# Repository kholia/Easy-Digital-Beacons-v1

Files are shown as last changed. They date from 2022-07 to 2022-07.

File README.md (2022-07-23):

### Easy-Digital-Beacons-v1

A simple and easy WiFi-enabled ESP8266-powered WSPR, FT8, and FT4 beacon system
which uses NTP + DS3231 RTC for timing. Also, checkout our [cost-effective, and
robust HF 5W PA system](https://github.com/kholia/HF-PA-v5/).

It is also a WiFi-enabled VFO, which is quite useful, and convenient for radio
experimentation work.

Note: The whole project can be assembled on a breadboard (including the [250mW
amplifier](./QRPp-Amplifier)) in under 30 minutes - do give it a go ;)

The whole design is modular, parametric (cost and others), field repairable,
and super extensible. It is almost trivial to add support for more `beacon
modes`.

#### Build Steps

If you are using Windows OS, execute the following steps:

- Download this repository by [clicking here](https://github.com/kholia/Easy-Digital-Beacons-v1/archive/refs/heads/master.zip).

- Extract the downloaded zip file to a folder.

- Run the `setup_arduino_ide.bat` file inside this folder.

- Install https://github.com/me-no-dev/ESPAsyncWebServer library.

- Install https://github.com/me-no-dev/ESPAsyncTC library.

If you are on Linux, execute the following steps:

```
sudo apt-get install git  # install 'git' if needed

git clone https://github.com/kholia/Easy-Digital-Beacons-v1.git

make install_arduino_cli
make install_platform
make deps  # using Windows?, read the 'Makefile' file

cd ~/Arduino/libraries
git clone https://github.com/me-no-dev/ESPAsyncWebServer.git
git clone https://github.com/me-no-dev/ESPAsyncTCP.git
```

Now execute these common steps:

Add your WiFi credentials in `Easy-Digital-Beacons-v4/credentials.h` file

Change the following lines in the code to use your values:

```
char message[] = "VU3CER VU3FOE MK68";
char call[] = "VU3FOE";
char loc[] = "MK68";
uint8_t dbm = 27;
```

[OPTIONAL] Change the following line in the code to suit your Si5351A module:

```
int32_t si5351CalibrationFactor =  ...
```

Use [this program](https://github.com/etherkit/Si5351Arduino/blob/master/examples/si5351_calibration/si5351_calibration.ino)
to derive the calibration value for your Si5351A module.

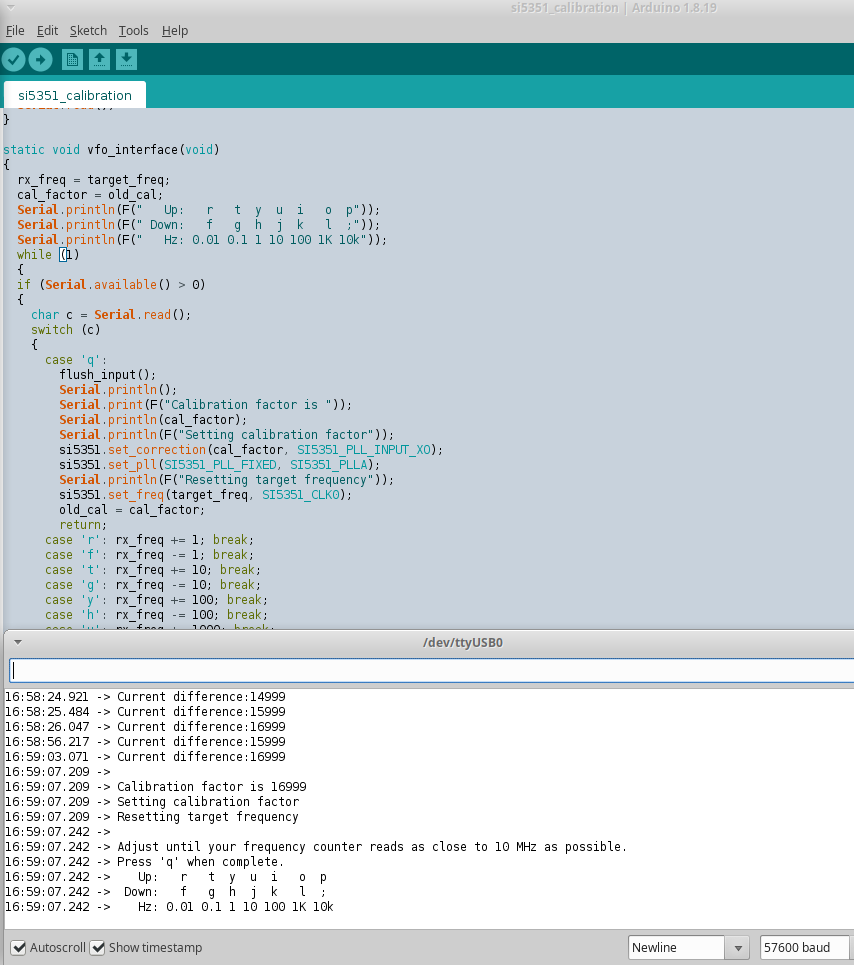
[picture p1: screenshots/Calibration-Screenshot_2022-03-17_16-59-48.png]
Si5351A Calibration


Follow [this tutorial first](https://randomnerdtutorials.com/esp8266-web-server-spiffs-nodemcu/) to
get familiar with `SPIFFS` uploading stuff. Use the `Tools -> ESP8266 Sketch
Data Upload` option in the Arduino IDE to upload the webserver resources to
ESP8266. Note: The webserver resources are located in the `data` folder
inside the `Easy-Digital-Beacons-v4` sketch.

Open and upload the `Easy-Digital-Beacons-v4` sketch to ESP8266 using the
`Sketch -> Upload` option in the Arduino IDE.

You are all set for the next step - congrats!

#### Usage

Turn off the `SW1` switch, and reboot the beacon system. The beacon system now
connects to your WiFi, and then runs a web server.

This web server can be accessed at http://beacon.local URL typically.

Beacon's web interface:

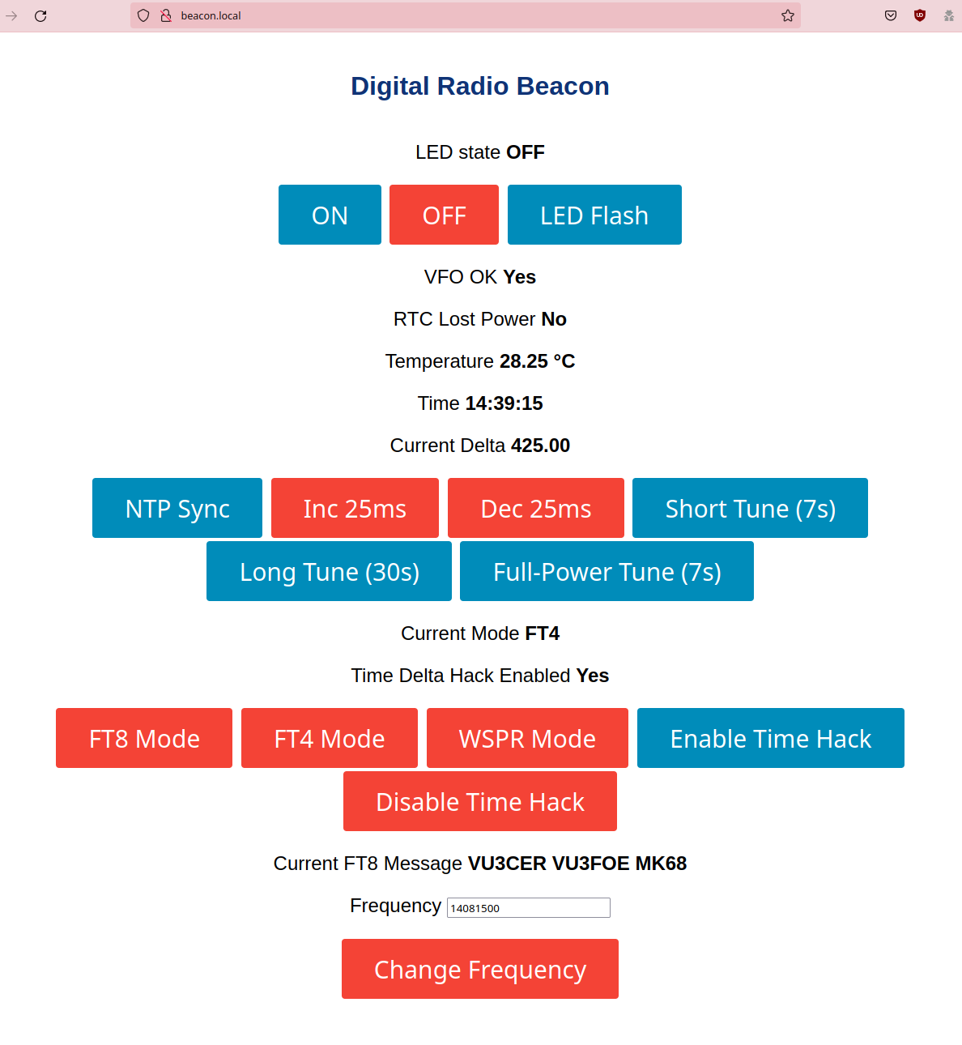
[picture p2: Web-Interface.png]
DEMO 2


Use this web interface to configure the beacon. Please use the `NTP Sync`
option in this web interface to set the RTC time fairly correctly.

Now, turn on the `SW1` switch, and reboot the beacon system. The beacon system
is active now, and will TX as per the configuration.

TIP: Please use a local (or nearby) receiver to receive and decode the beacon
signals! This is important to ensure that your beacon is TX'ing correctly.

Pinout 1


Si5351A module is connected via I2C to pins D1 (SCL) and D2 (SDA) of the Wemos
D1 Mini board. Connect DS3231 similarly.

Here is the schematic for the `Easy-Digital-Beacons-v4` sketch:

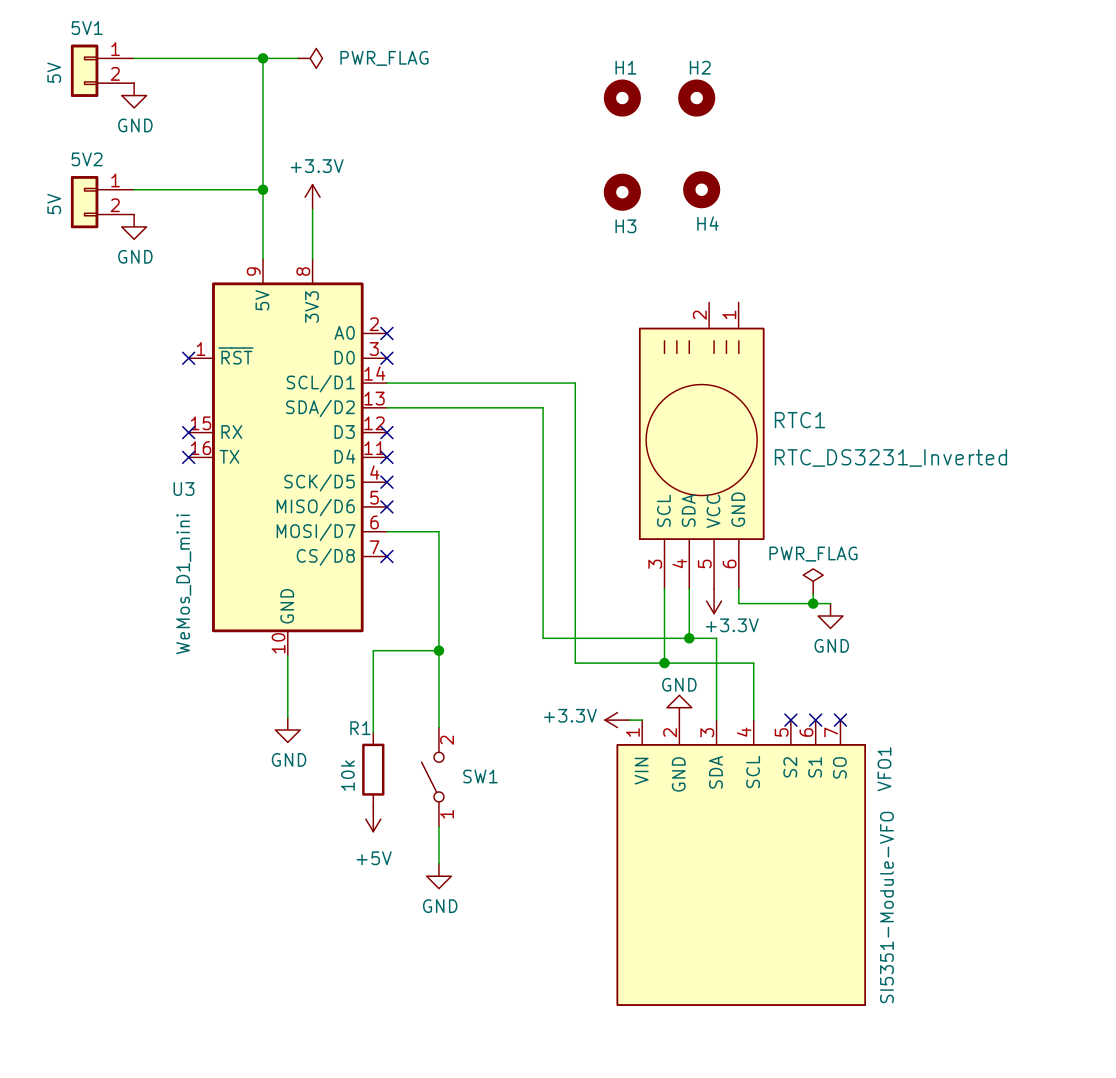
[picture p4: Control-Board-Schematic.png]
Schematic


For troubleshooting, you may want to try the following similar project by the
awesome WB2CBA:

- https://antrak.org.tr/blog/esp-wspr-simple-and-inexpensive-wspr-transmitter/
- https://antrak.org.tr/blog/a-whisper-wspr-adventure-and-esp_wspr/

#### Notes

Note 2 (March-2022): The `FT4` beacon is decently reliable now (all thanks to
Anupam).

Author: Dhiru Kholia (VU3CER) - https://www.qrz.com/db/VU3CER/

Author 2: Anupam Saikia - https://github.com/anupamsaikia

The `DT` timings are very nice with `NTP Sync`, `DS3231 RTC` and the optional
`time-delta hack`.

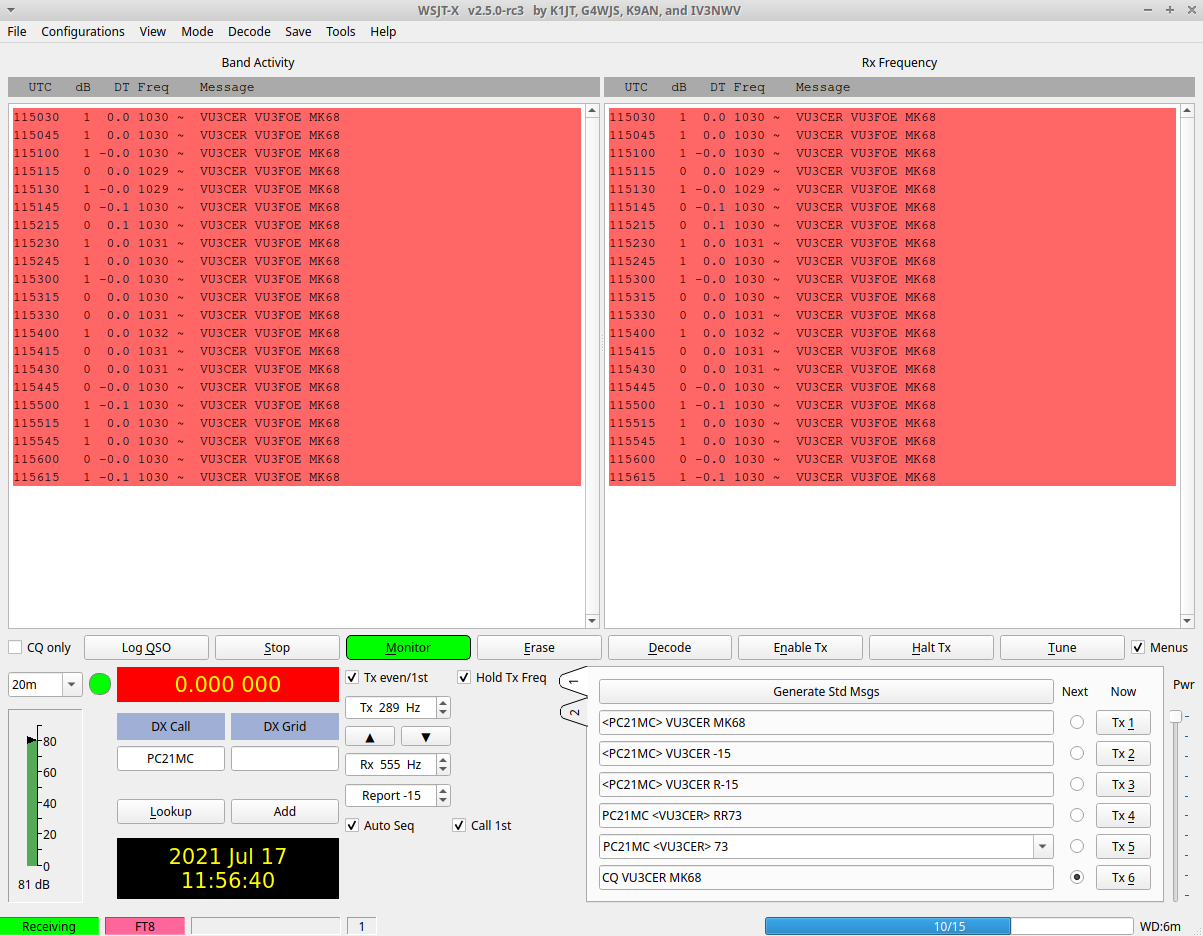
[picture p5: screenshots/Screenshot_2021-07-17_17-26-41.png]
DEMO 0


7W (or less) of HF RF power offers global communications coverage when
propagation is good:

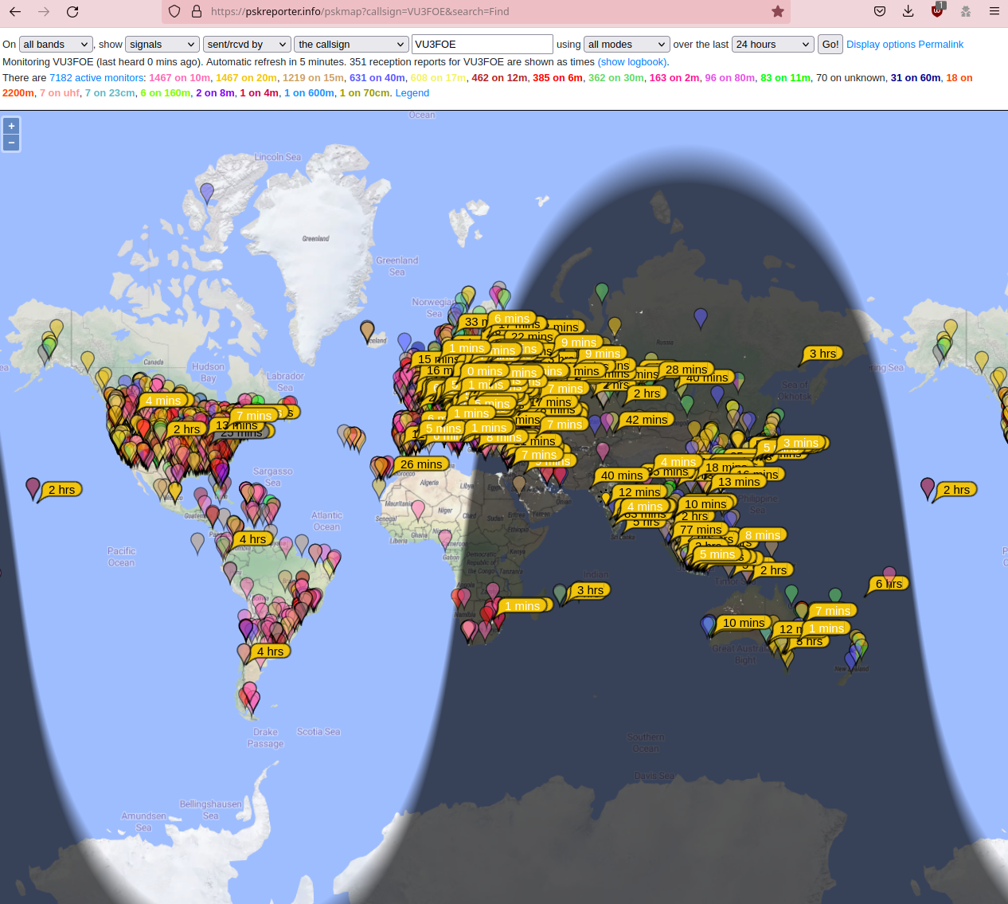
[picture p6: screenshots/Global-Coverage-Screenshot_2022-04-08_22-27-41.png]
Global Coverage

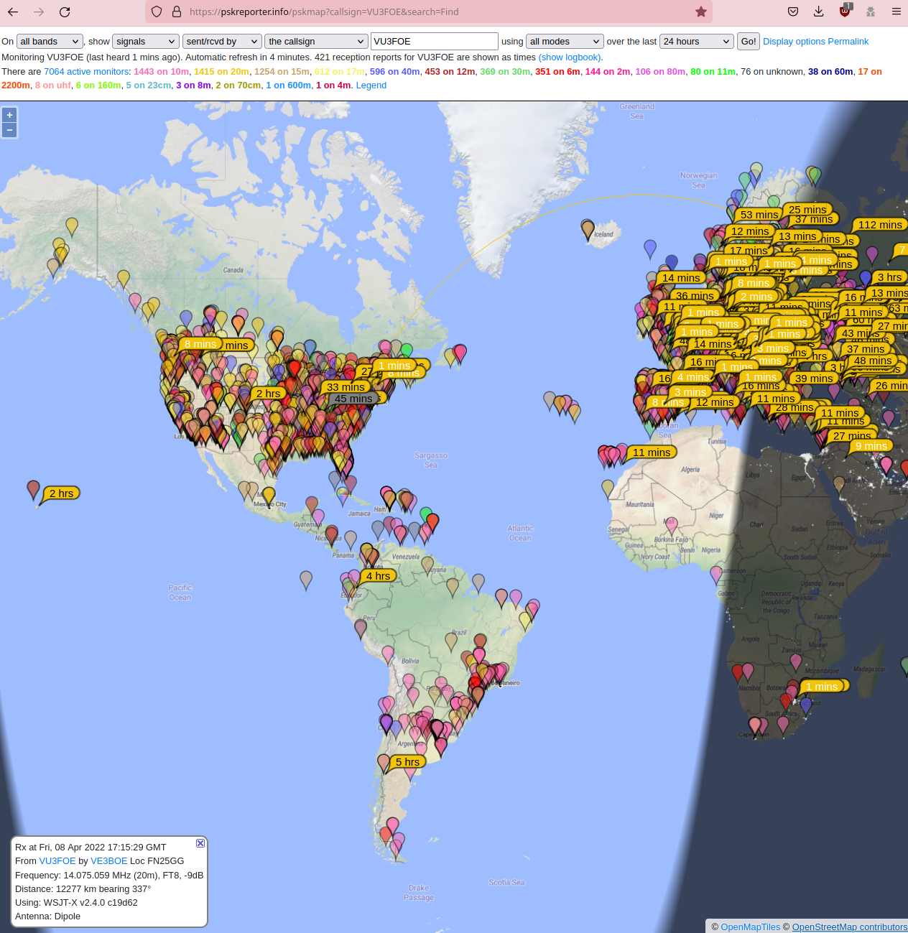
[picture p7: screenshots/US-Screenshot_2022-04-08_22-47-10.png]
US - Many Spots


WSPR mode demo:

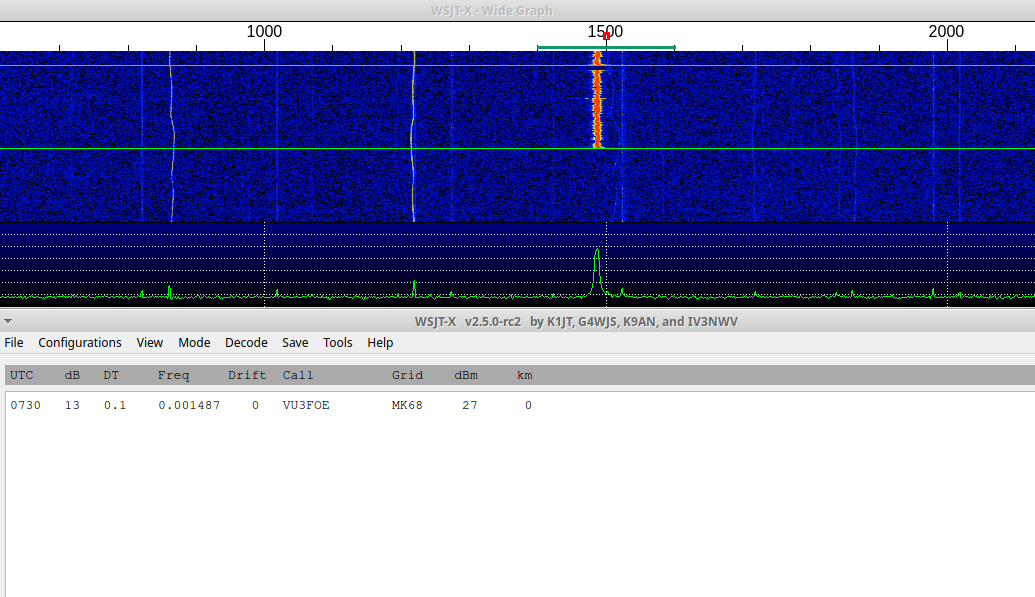
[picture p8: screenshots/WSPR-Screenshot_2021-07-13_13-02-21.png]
DEMO 1


Sample 3D rendering:

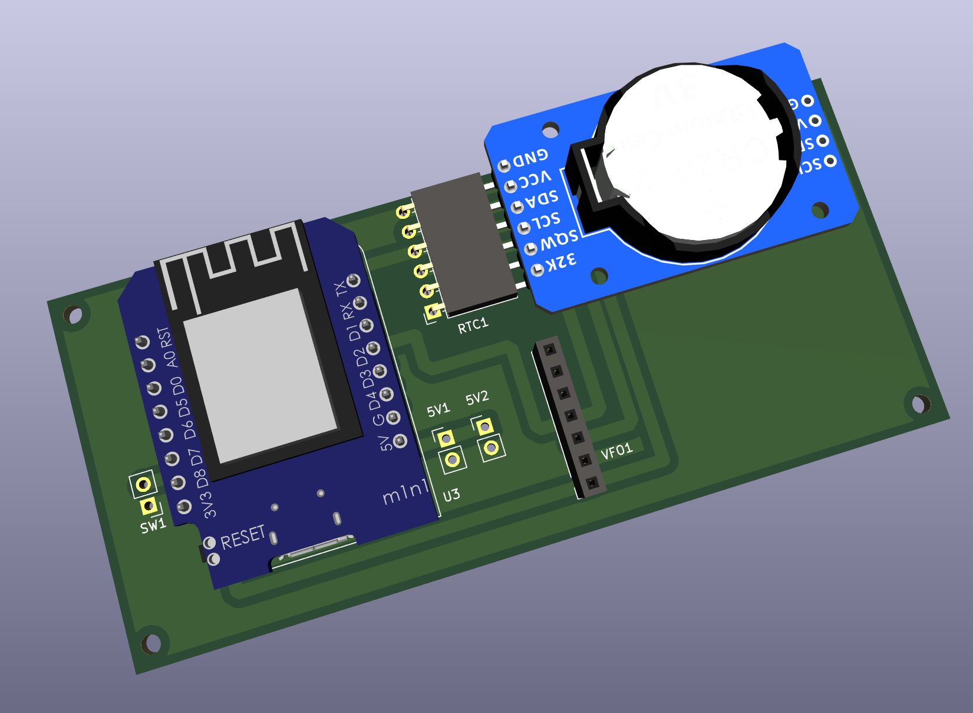
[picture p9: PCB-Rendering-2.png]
DEMO 3


Note: This 3D rendering is *only* published to help with the manual layout work
on Zero-PCBs. The current PCB version is just a placeholder hack - more to come
soon!

FT4 mode demo:

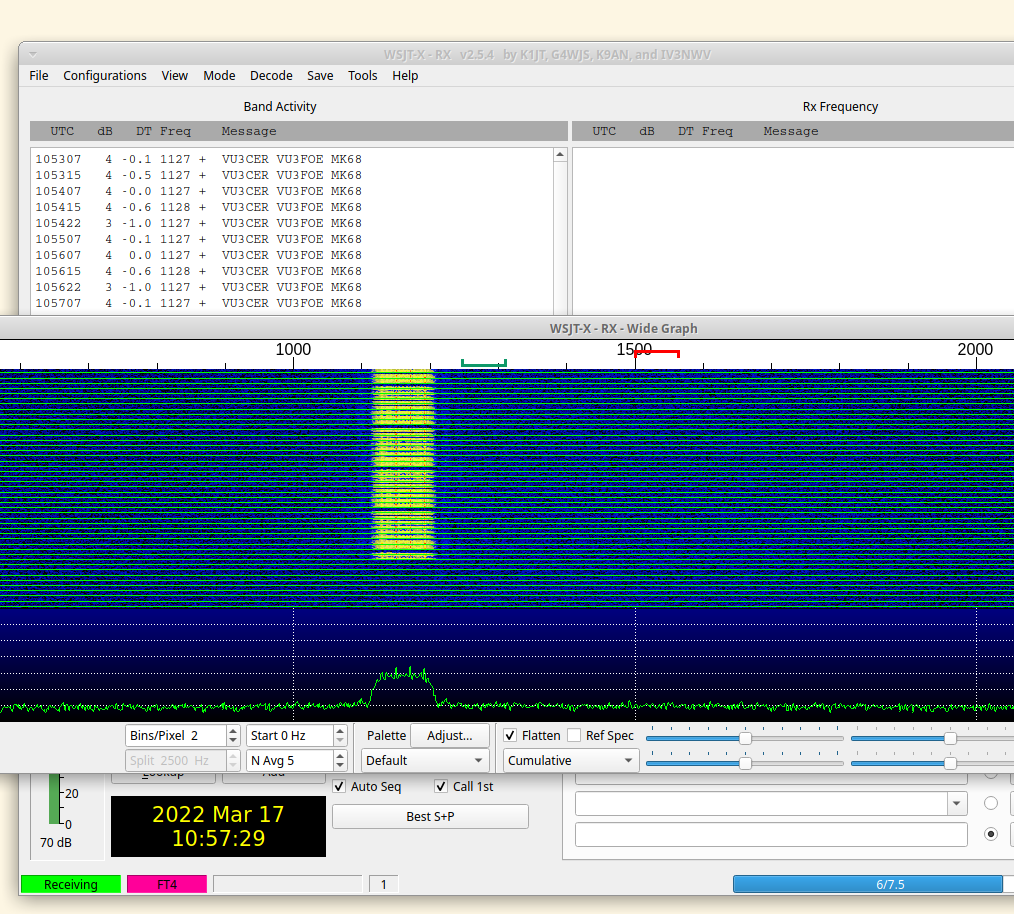
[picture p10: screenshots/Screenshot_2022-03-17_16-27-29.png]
FT4 1


FST4W mode demo:

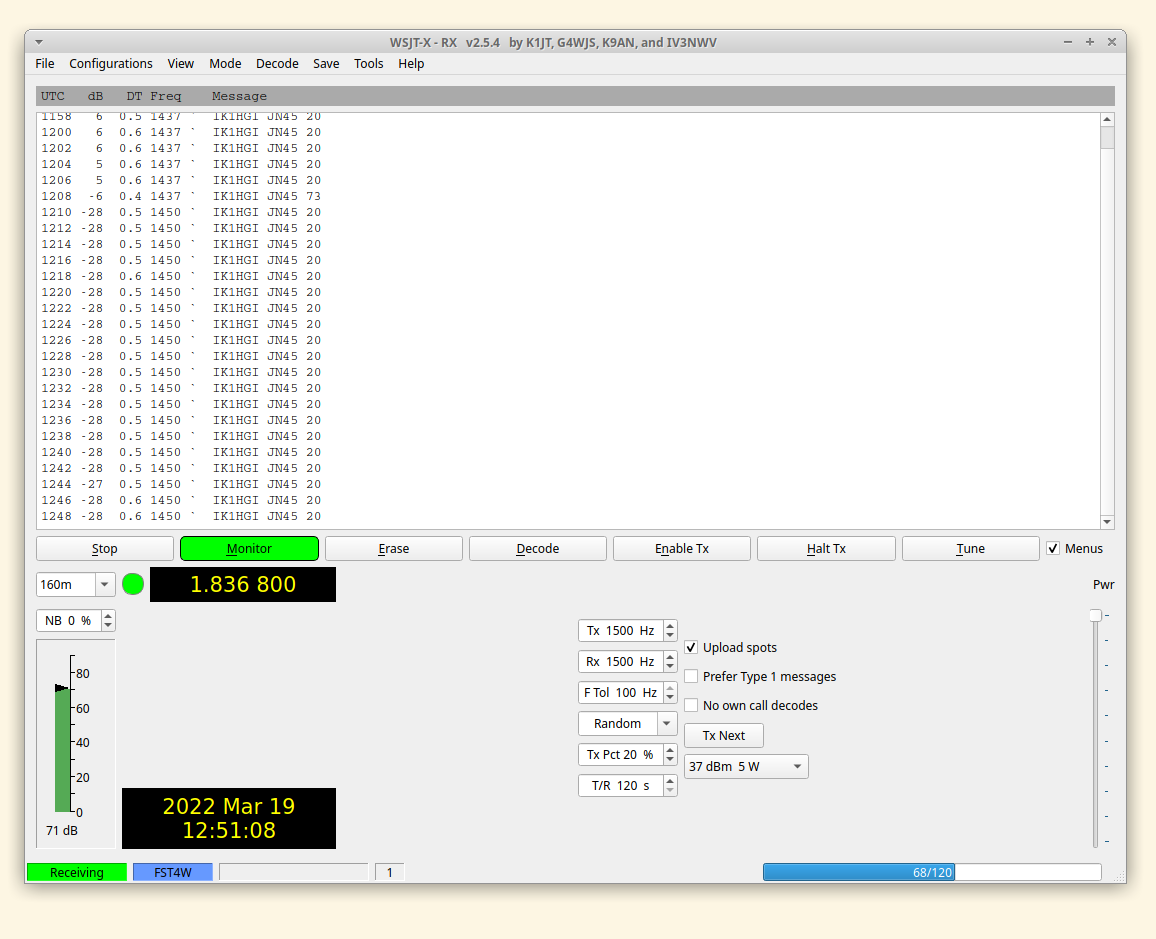
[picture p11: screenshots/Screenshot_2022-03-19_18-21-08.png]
FST4W 1


#### Battery System Recommendation

I recommend using a LiFePo4 (LFP) battery which has good energy density and is
also priced decently well.

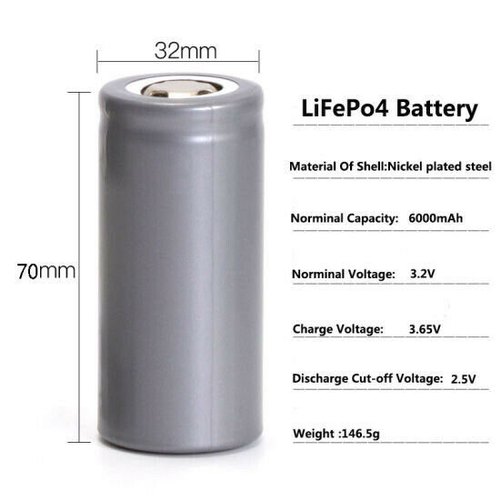
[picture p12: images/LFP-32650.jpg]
32650 battery


Use the LFP battery with a `1S LFP BMS`.

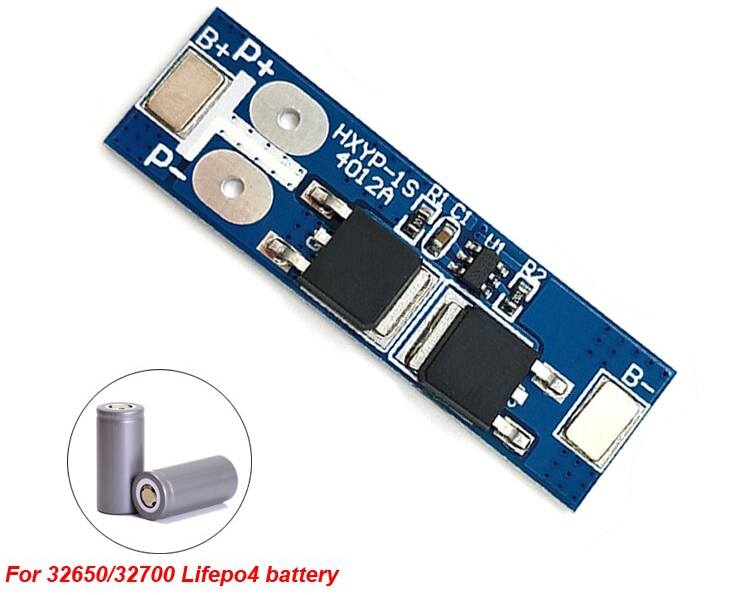
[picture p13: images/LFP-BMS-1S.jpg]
1S LFP BMS


The BMS' output can be connected directly to the 3.3v input of the ESP8266
module.

#### NTP (Time) Sync for FST4W-Antonio

In the Arduino IDE, select `Tools -> Serial Monitor`. In the `Serial Monitor`
send `s` character to ESP8266 to trigger the `NTP Time Sync` process.

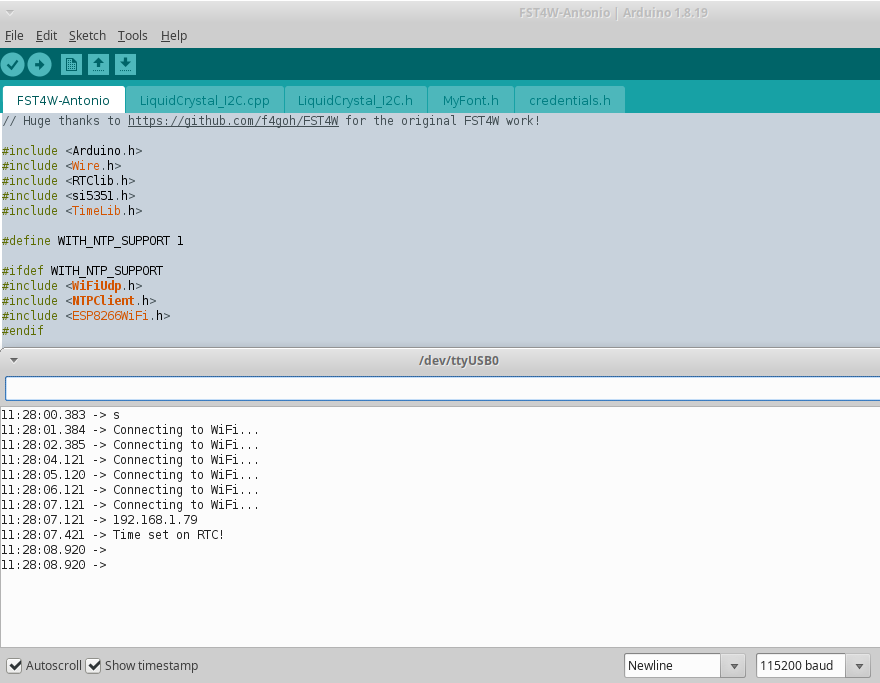
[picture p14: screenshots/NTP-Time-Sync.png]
NTP Time Sync


Reboot ESP8266 to check if RTC is retaining the correct time. If not, change
the RTC battery.

#### Power Notes

This will need a HF RF PA in most cases to be usable on the air.

UPDATE (May 2022): Checkout our [cost-effective, and robust HF PA system](https://github.com/kholia/HF-PA-v6/).

You can also start with the easy-to-build and breadboard-friendly [QRPp-Amplifier](./QRPp-Amplifier).

#### Relay Usage

We use a 2-channel relay as a `T/R switch`.

See https://github.com/kholia/Simple-TR-Switch for details.

Also check out https://github.com/kholia/Easy-Transceiver project.

#### BOM

- 1 x 3/5mm LED (purple or pink is recommended)

- 1 x small regular (spst) chassis mount switch

- 1 x 0.25w 470 ohm resistor (CFR / MFR)

- Relimate male connectors

- Relimate female-female cables

- Female berg strips

- Zero PCB of a suitable size

Si5351A Module:

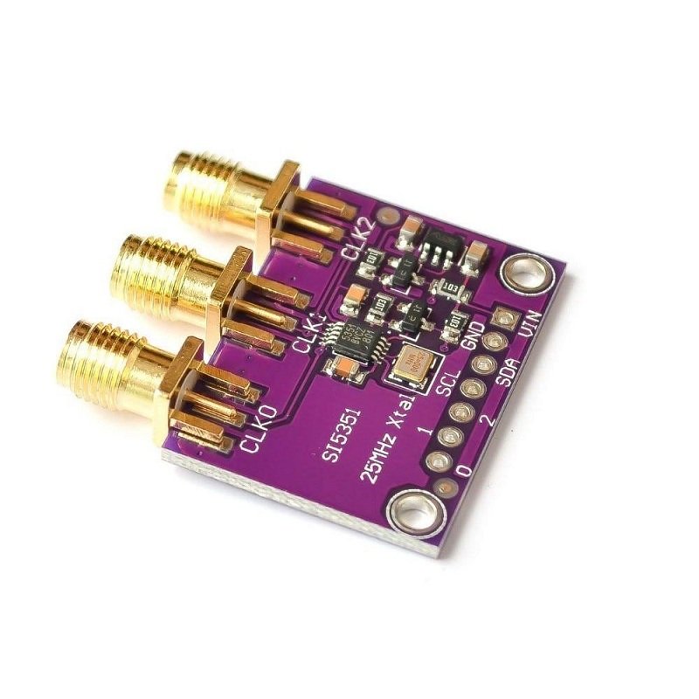
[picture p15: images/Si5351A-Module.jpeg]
Part 1


DS3231 RTC Module:

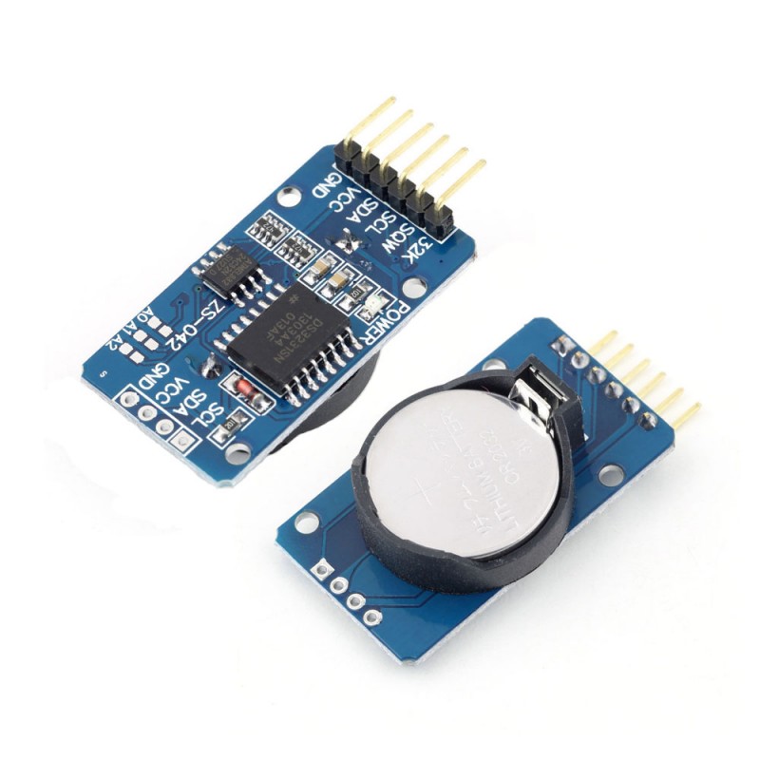
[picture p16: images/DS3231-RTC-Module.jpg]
Part 2


μC Board:

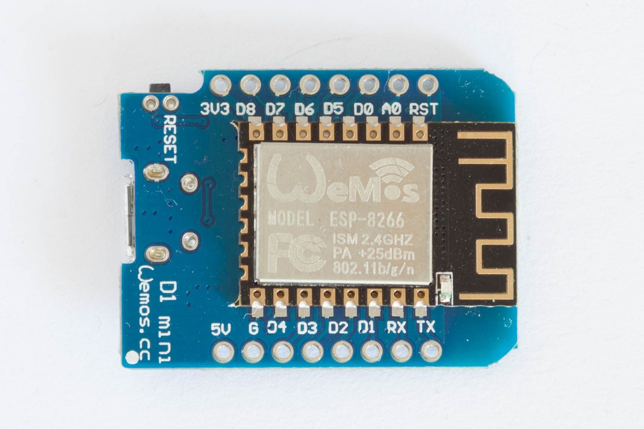
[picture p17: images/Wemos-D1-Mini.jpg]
Part 3


OLED screen (optional):

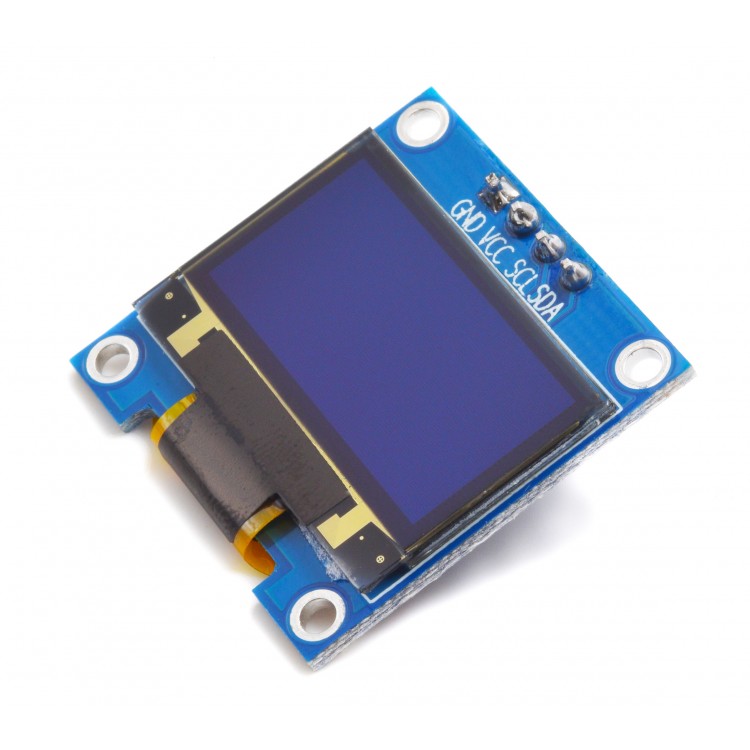
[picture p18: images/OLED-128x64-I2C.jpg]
Part 4


#### BOM Sources

- https://robu.in/

- https://www.electronicscomp.com/

- https://projectpoint.in/

#### Tips

Useful commands:

```
pacmd load-module module-null-sink sink_name=Virtual0
pacmd update-sink-proplist Virtual0 device.description=Virtual0
pacmd update-source-proplist Virtual0.monitor device.description=Virtual0
```

Use Gqrx and WSJT-X with a SDR device for initial frequency adjustment /
calibration. This is essential for WSPR functionality. FT8 is more
robust/tolerant of frequency deviations due to a much larger RX window.

Note: To customize the FST4W beacon to use your callsign and grid, use the
following commands to generate the `FST4Wsymbols` array data.

```
fst4sim.exe "IK1HGI JN45 20" 60 1500 0.0 0.1 1.0 10 -15 F > message.txt

message2array.exe message.txt
```

Replace the original `FST4Wsymbols` array data with the output of
`message2array.exe` program.

#### Future Tasks

- Change Si5351 calibration factor from the Web UI

- Add support for custom FT8 / FT4 messages

- Re-announce mDNS stuff [LP]

- EEPROM - save TX interval / schedule [LP]

- Reset to defaults button [LP]

#### References + Credits

- https://github.com/kholia/Easy-Transceiver

- https://github.com/kgoba/ft8_lib

- https://github.com/etherkit/JTEncode

- https://github.com/Naguissa/uEEPROMLib

- https://randomnerdtutorials.com/esp8266-web-server-spiffs-nodemcu/

- https://lastminuteengineers.com/ds3231-rtc-arduino-tutorial/

- https://learn.adafruit.com/adafruit-si5351-clock-generator-breakout/wiring-and-test

- https://github.com/agustinmartino/wsjt_transceiver

- https://github.com/agustinmartino/wsjtx_transceiver_interface

- https://www.qrp-labs.com/synth/ms5351m.html

- https://github.com/anupamsaikia - FT4 fixes - thanks!

- https://github.com/f4goh/WSPR (pretty cool)

- https://github.com/lu7did/PixiePi

- https://github.com/iw5ejm/multibandWSPR_nodeMCU

- https://km4nmp.com/2019/08/24/vfo-for-the-pixie-wiring-and-sketch-for-ad9850/

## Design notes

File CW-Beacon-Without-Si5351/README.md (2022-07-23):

Firmware can be downloaded from https://github.com/kholia/pico-cw-beacon-drs page.

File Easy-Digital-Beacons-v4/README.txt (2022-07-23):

Install the following libraries in the Arduino IDE.

https://github.com/me-no-dev/ESPAsyncTCP

https://github.com/me-no-dev/ESPAsyncWebServer

This version (Easy-Digital-Beacons-v4) operates with https://github.com/kholia/HF-PA-v5 (and others).

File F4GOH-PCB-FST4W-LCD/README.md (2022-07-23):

This program adds GPS functionality to the following code:

https://github.com/f4goh/WSPR/tree/master/src/IK1HGI/wsprEncode

Note: Connect TX pin of the NEO-6M GPS module to pin `D4` of Arduino Nano or to
the `TXGPS` pin on the F4GOH PCB board.

Connect `D3` pin to an external LED (via a resistor) for `GPS SYNC` indication.

On Arduino startup, it will automatically try to do a GPS time sync.

Launch the `Serial Monitor` (at a baud rate of 9600) and send the `g` command
to trigger a GPS update manually.

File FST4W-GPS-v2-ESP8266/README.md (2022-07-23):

Connect TX pin of the NEO-6M GPS module to pin `D7` of WeMos D1 mini.

Connect `D5` pin to an external LED (via a resistor) for TX indication.

Connect `D6` pin to an external LED (via a resistor) for `GPS SYNC` indication.

On ESP8266 startup, it will automatically try to do a GPS time sync for a
~minute.

Please power the `I2C LCD Display (16x2)` using 5v. It works poorly with
3.3v.

Launch the `Serial Monitor` (at a baud rate of 9600) and send the `g` command
to trigger a GPS update manually.

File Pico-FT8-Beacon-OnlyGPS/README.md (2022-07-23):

#### Connections

Pin 1 (GP0) is SDA and Pin 2 (GP1) is SCL - connect Si5351 module to these
pins. Connect GPS's TX pin to pin 12 (GP9) of Pi Pico.

#### Credits

- https://github.com/earlephilhower/arduino-pico

- https://github.com/etherkit/Si5351Arduino/blob/master/src/si5351.cpp

- https://github.com/kgoba/ft8_lib/

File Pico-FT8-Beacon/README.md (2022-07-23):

#### Connections

Pin 1 is SDA. Pin 2 is SCL. Connect GPS's TX pin to pin 12 of Pi Pico.

#### Credits

- https://github.com/earlephilhower/arduino-pico

- https://github.com/etherkit/Si5351Arduino/blob/master/src/si5351.cpp

- https://github.com/kgoba/ft8_lib/

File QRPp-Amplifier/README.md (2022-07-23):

#### Schematic

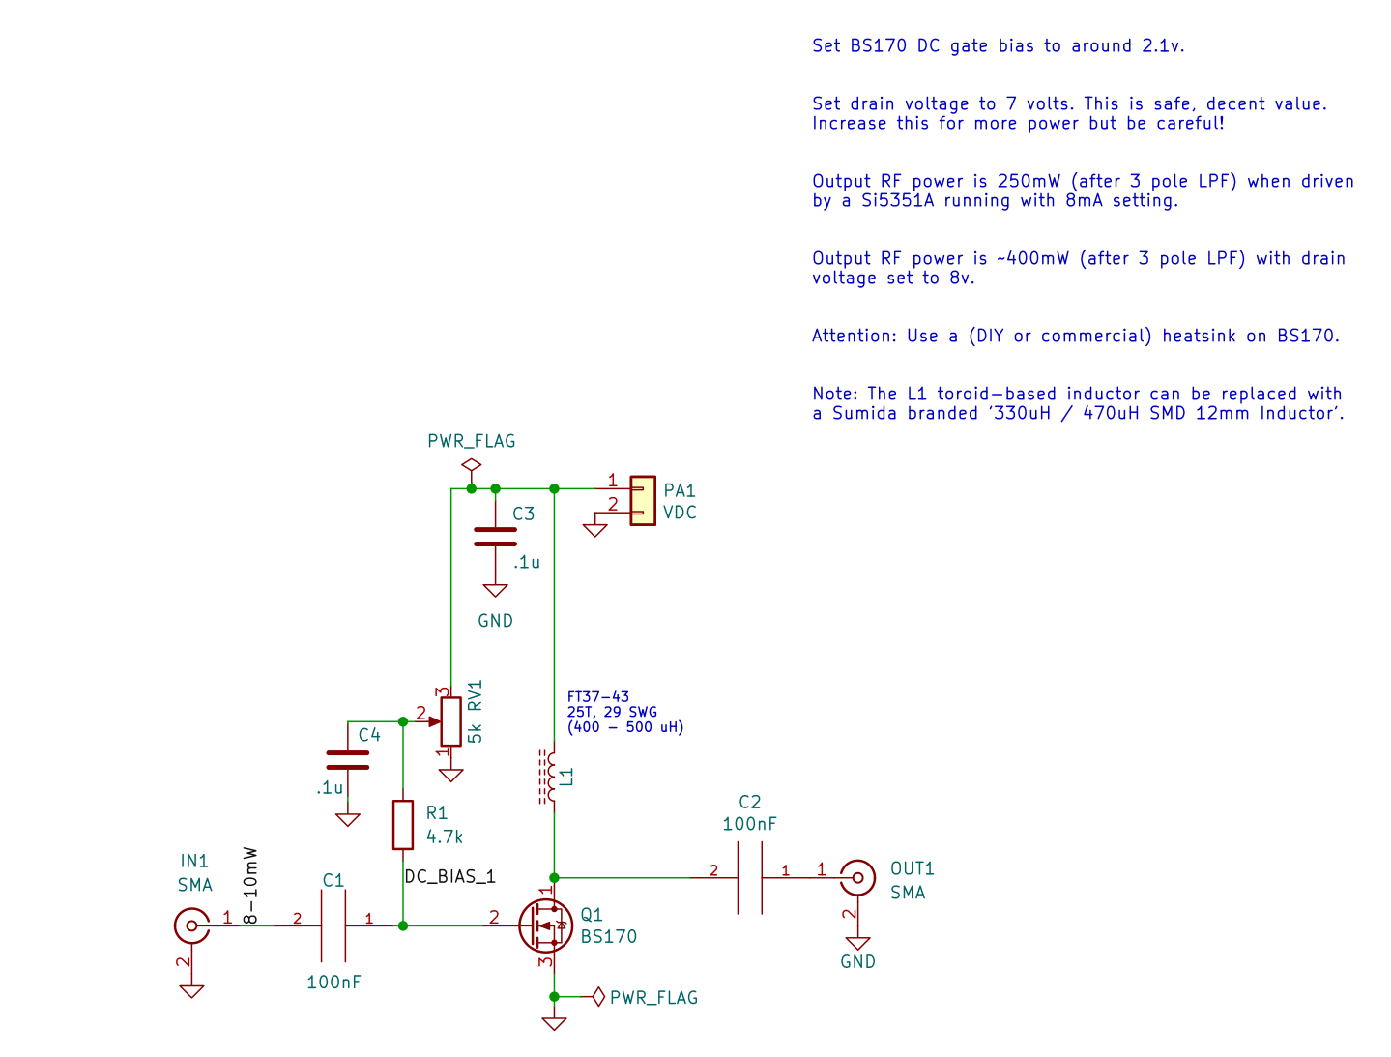
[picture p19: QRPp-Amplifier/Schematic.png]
Schematic


#### References

- https://www.instructables.com/DIY-Heatsink-for-Small-Transistors/ is superb

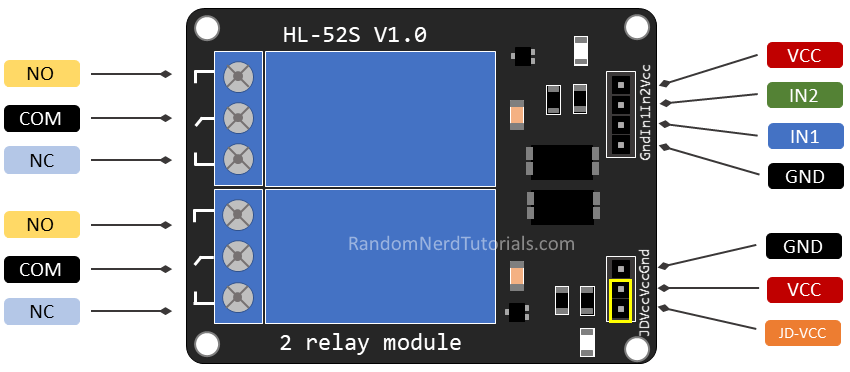
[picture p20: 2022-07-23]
images/Relay-pinout.png

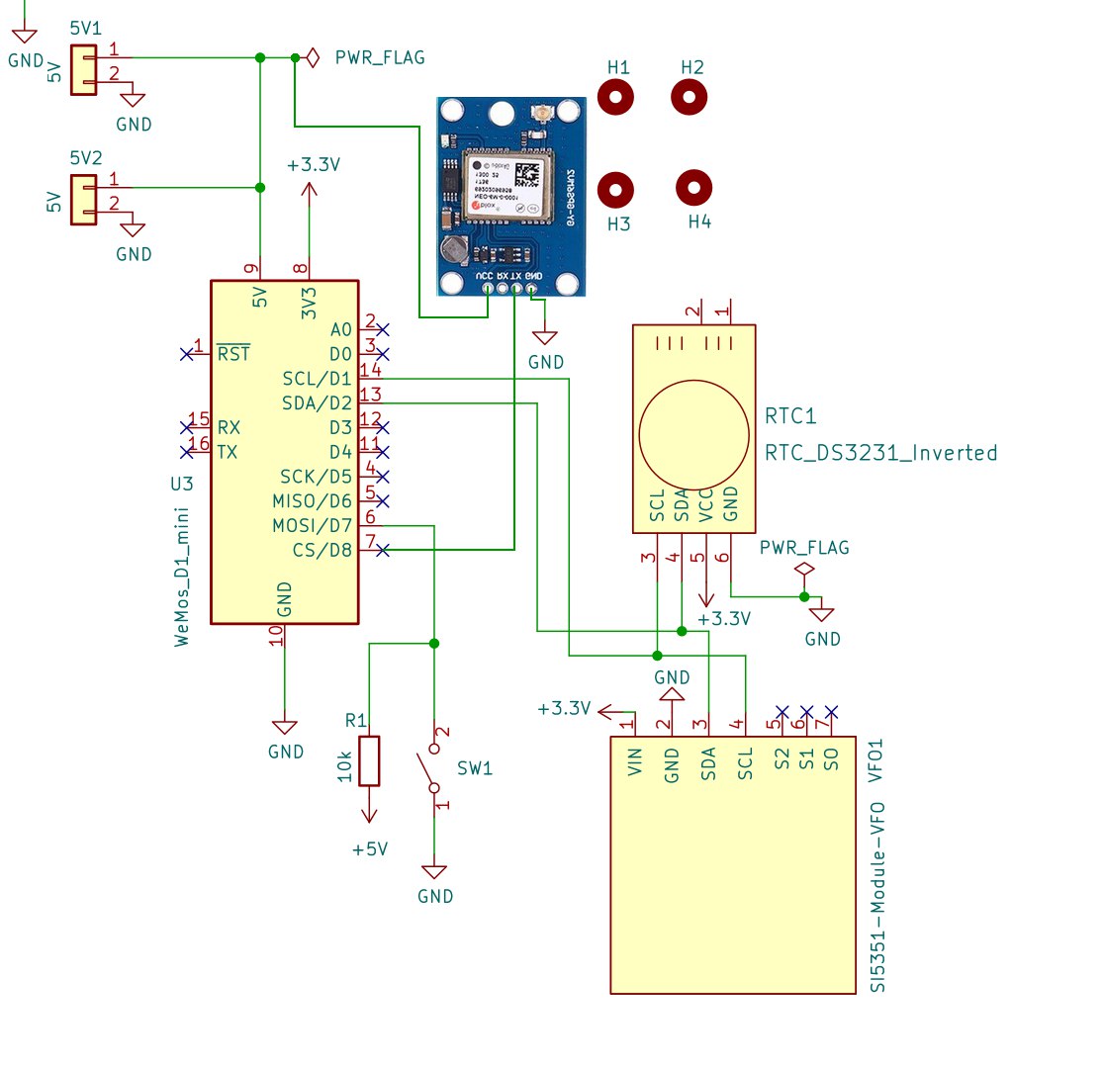
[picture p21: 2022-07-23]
images/Tony-Schematic.jpeg

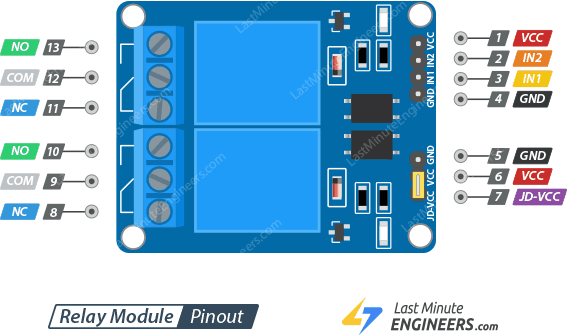
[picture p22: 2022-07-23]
images/relay-module-pinout.png

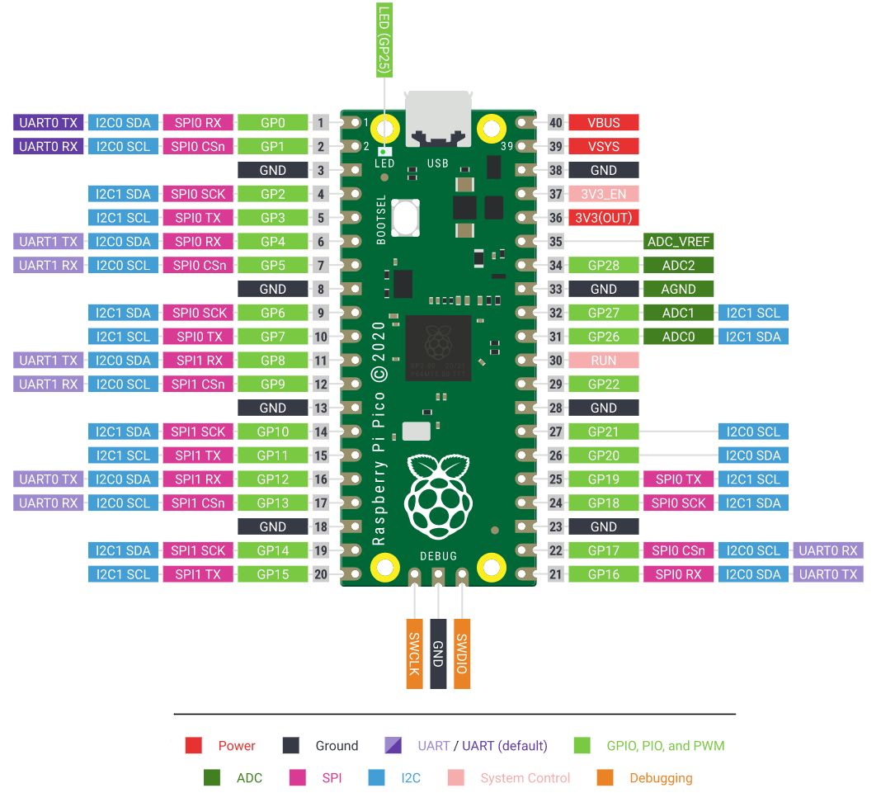
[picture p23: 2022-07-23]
Pico-FT8-Beacon-OnlyGPS/raspberry_pi_Pico-R3-Pinout-narrow.png

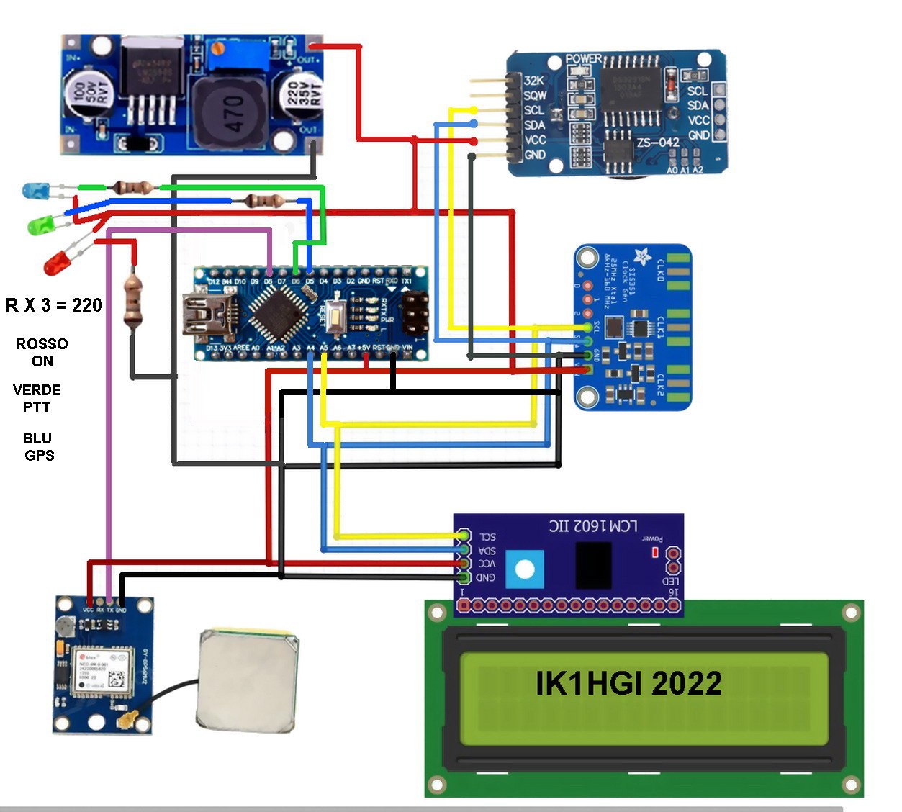
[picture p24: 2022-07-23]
WSPR-GPS-Antonio-Arduino/WSPR-GPS-Schematic-From-Antonio.jpg

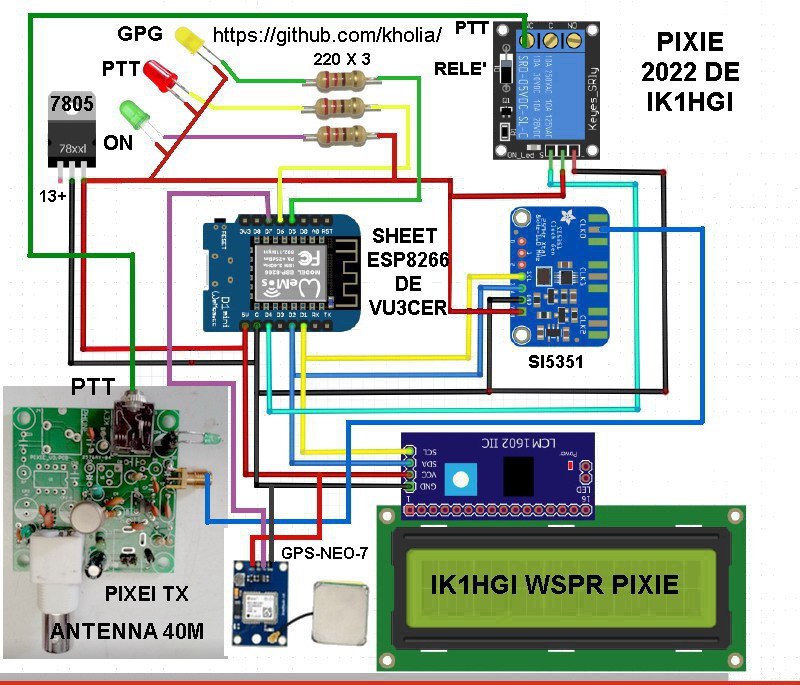
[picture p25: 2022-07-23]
Pixie-WSPR-ESP8266/Schematic.jpg

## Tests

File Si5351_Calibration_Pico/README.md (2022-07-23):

#### Connections

Note: Same pinout as `Pico-FT8-Beacon-OnlyGPS` from this repository.

#### Credits

- https://github.com/earlephilhower/arduino-pico

- https://github.com/etherkit/Si5351Arduino/blob/master/src/si5351.cpp

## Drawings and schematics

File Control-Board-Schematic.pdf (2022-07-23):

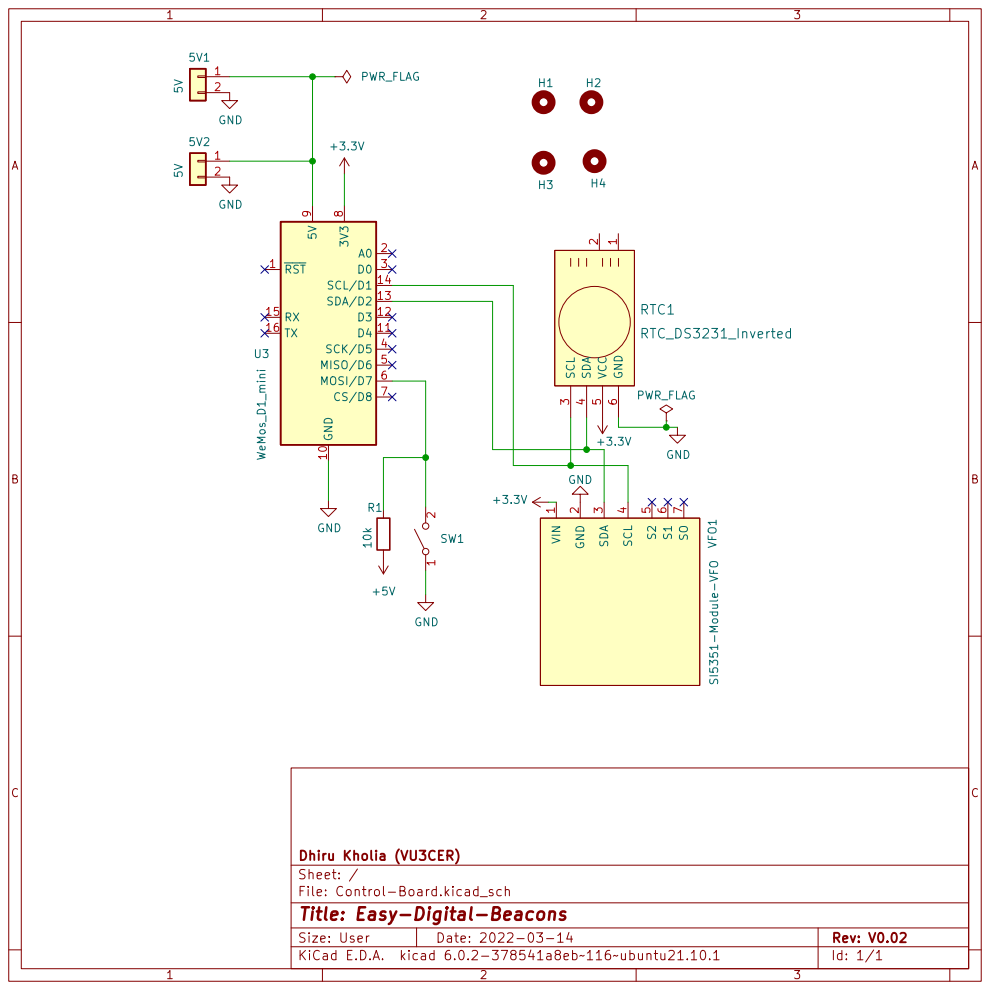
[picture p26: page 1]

File: Control-Board.kicad_sch Sheet: / Dhiru Kholia (VU3CER) GND

Id: 1/1 Title: Easy-Digital-Beacons

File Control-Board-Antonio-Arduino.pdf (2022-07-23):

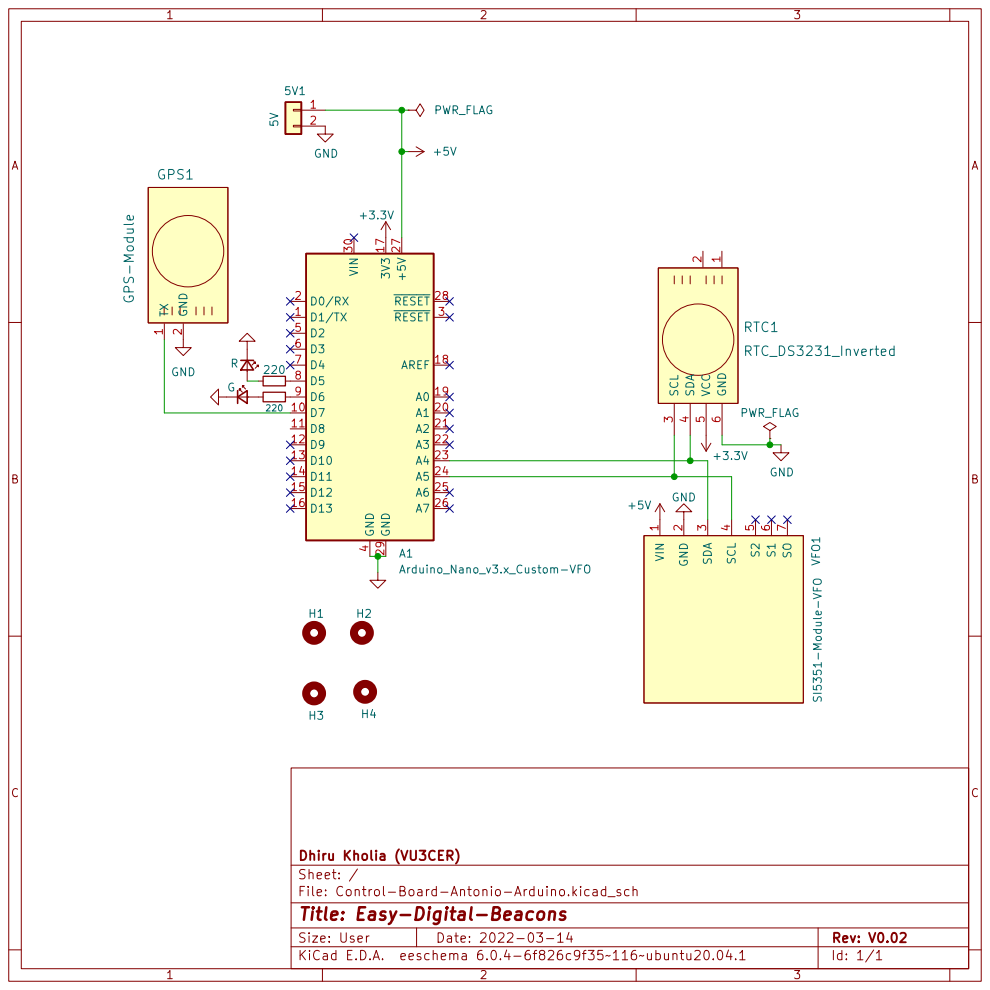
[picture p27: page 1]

2 GPS1 GPS-Module GND GND

Id: 1/1 Title: Easy-Digital-Beacons

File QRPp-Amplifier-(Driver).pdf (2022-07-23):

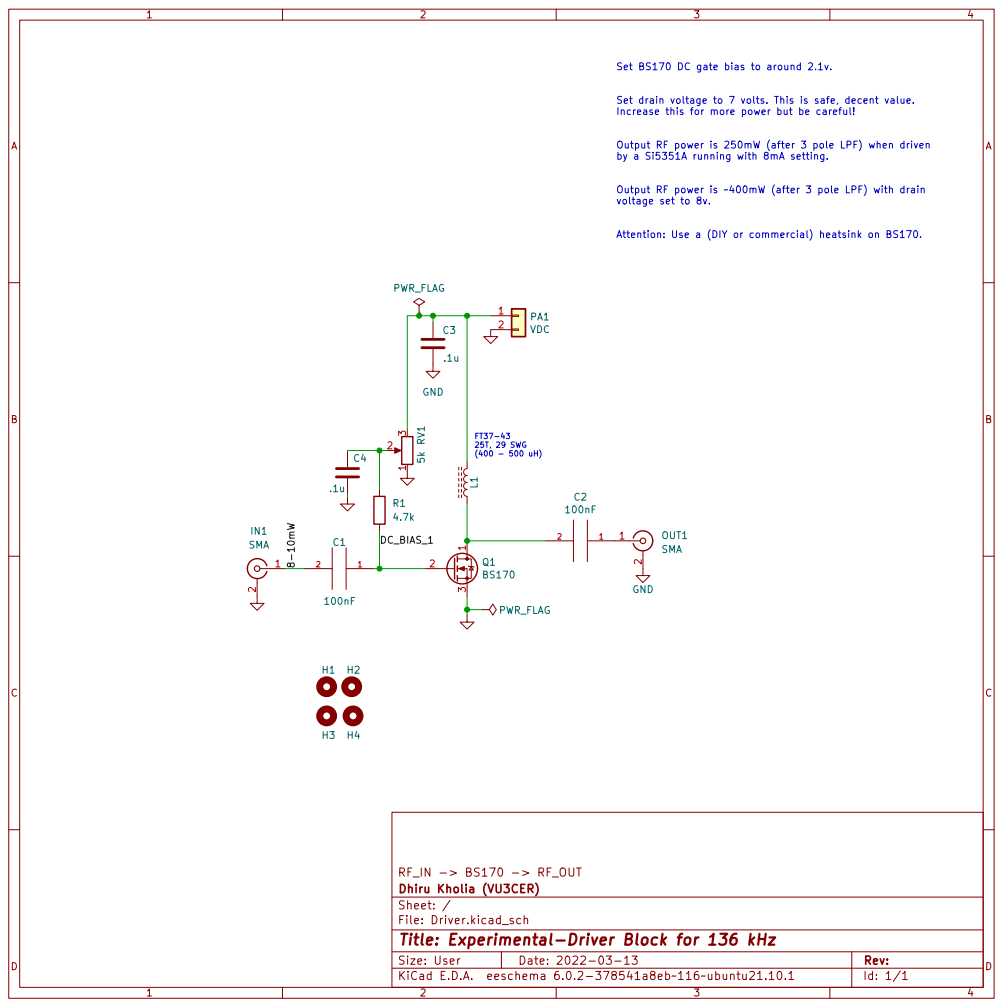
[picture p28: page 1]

Set drain voltage to 7 volts. This is safe, decent value.
Increase this for more power but be careful!

Output RF power is 250mW (after 3 pole LPF) when driven
by a Si5351A running with 8mA setting.

Output RF power is ~400mW (after 3 pole LPF) with drain
voltage set to 8v.

Attention: Use a (DIY or commercial) heatsink on BS170.

RF_IN -> BS170 -> RF_OUT
File: Driver.kicad_sch Sheet: / Dhiru Kholia (VU3CER)

Id: 1/1 Title: Experimental-Driver Block for 136 kHz

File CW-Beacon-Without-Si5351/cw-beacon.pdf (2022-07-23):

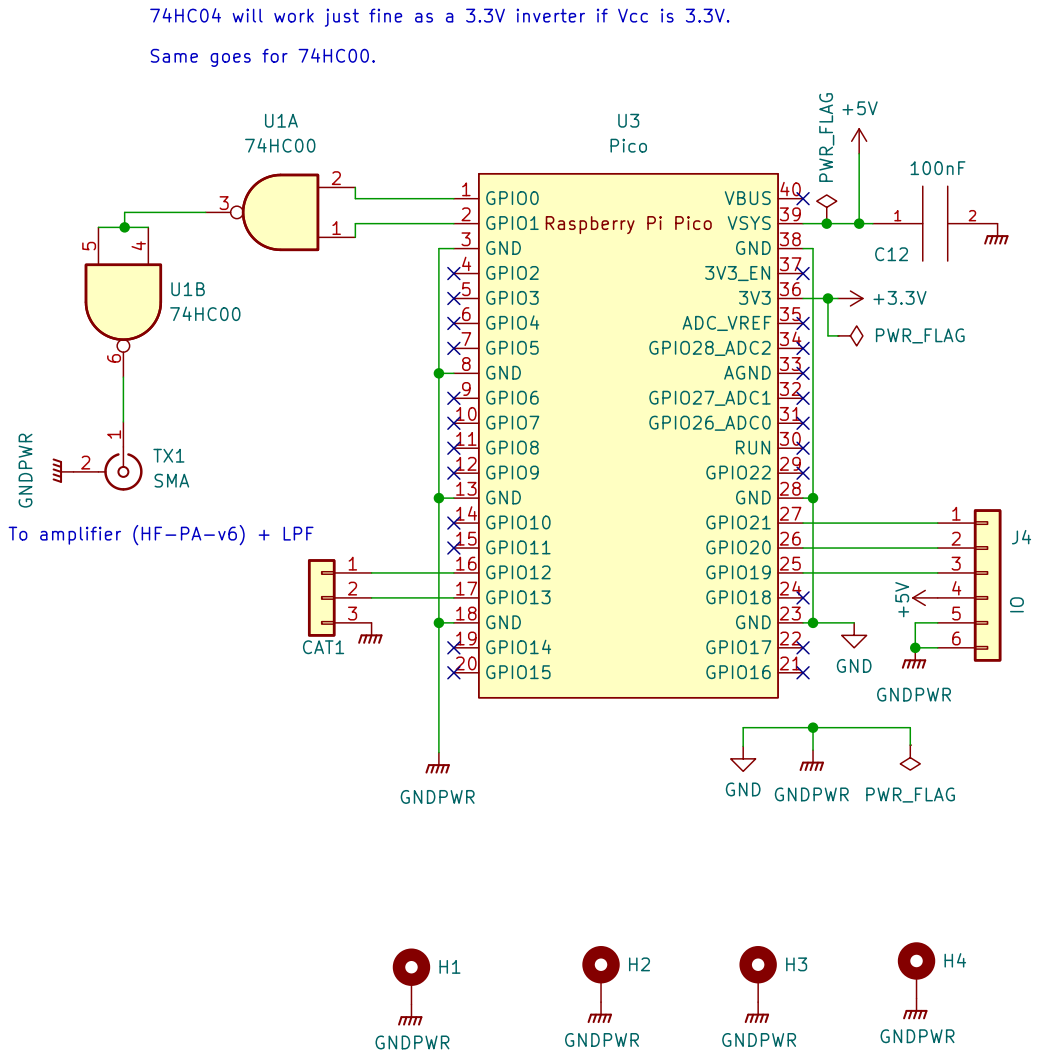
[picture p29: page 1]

74HC04 will work just fine as a 3.3V inverter if Vcc is 3.3V.

To amplifier (HF-PA-v6) + LPF

File: cw-beacon.kicad_sch Sheet: / VU3CER

Id: 1/1 Title: Easy CW Beacon without Si5351

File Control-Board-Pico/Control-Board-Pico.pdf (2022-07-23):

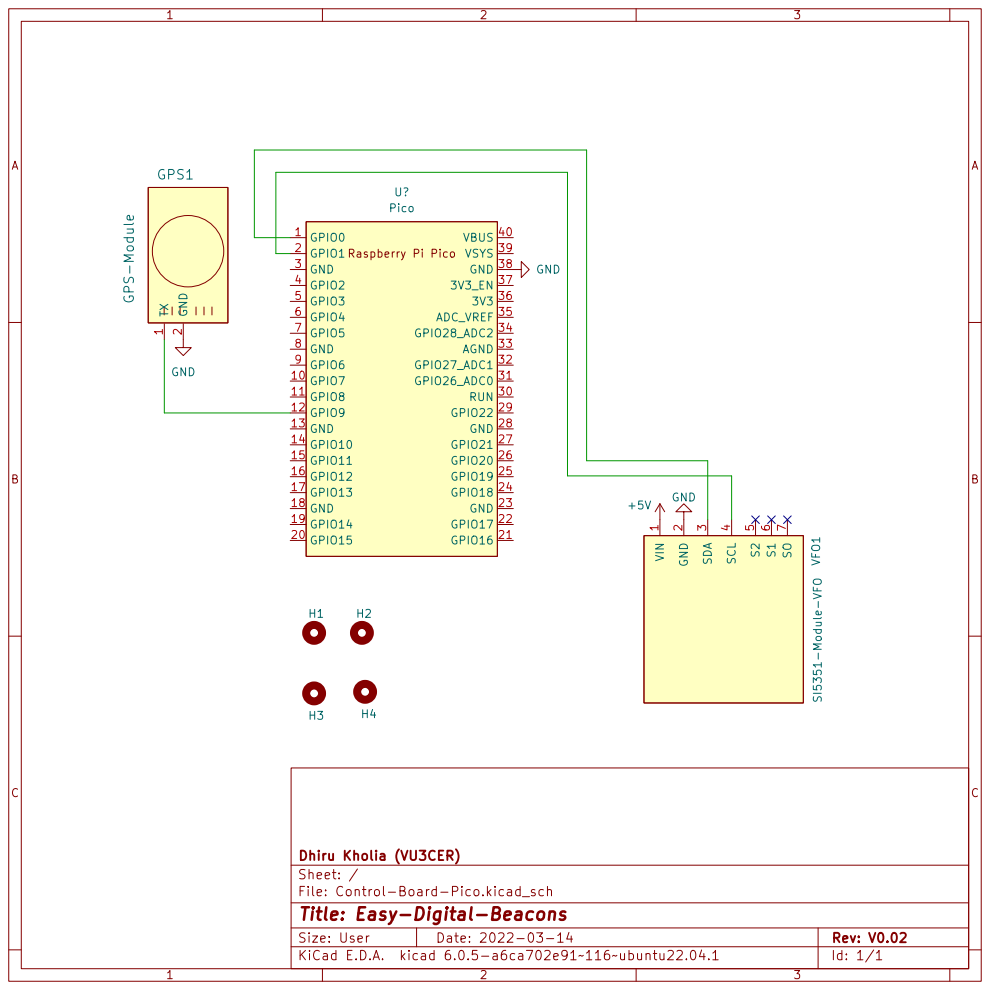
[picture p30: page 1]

Id: 1/1 Title: Easy-Digital-Beacons

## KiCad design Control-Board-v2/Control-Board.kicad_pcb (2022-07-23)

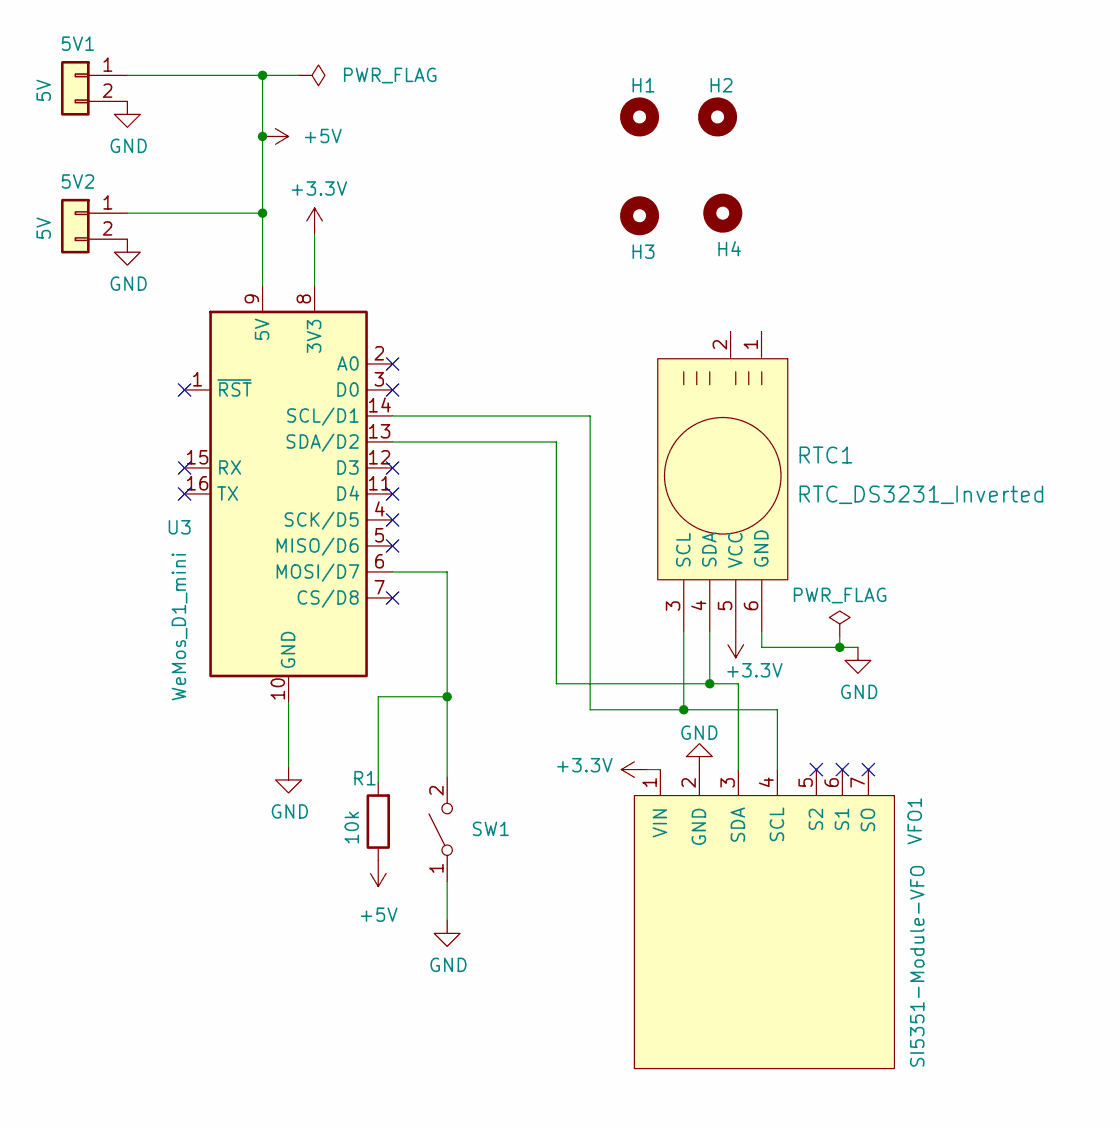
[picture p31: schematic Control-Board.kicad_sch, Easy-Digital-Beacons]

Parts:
5V1, 5V2: 5V; PinHeader_1x02_P2.54mm_Vertical
H1, H2, H3, H4: MountingHole; MountingHole_2.2mm_M2
R1: 10k; R_Axial_DIN0207_L6.3mm_D2.5mm_P7.62mm_Horizontal
RTC1: RTC_DS3231_Inverted; PinSocket_1x06_P2.54mm_Horizontal
SW1: SW_SPST; PinHeader_1x02_P2.54mm_Vertical
U3: WeMos_D1_mini; WEMOS_D1_mini_light
VFO1: SI5351-Module-VFO; PinSocket_1x07_P2.54mm_Vertical

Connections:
+3V3: RTC1.5 (VCC), U3.8 (3V3), VFO1.1 (VIN)
+5V: 5V1.1, 5V2.1, R1.1, U3.9 (5V)
GND: 5V1.2, 5V2.2, RTC1.6 (GND), SW1.1 (A), U3.10 (GND), VFO1.2 (GND)
unnamed: R1.2, SW1.2 (B), U3.6 (MOSI/D7)
unnamed: RTC1.3 (SCL), U3.14 (SCL/D1), VFO1.4 (SCL)
unnamed: RTC1.4 (SDA), U3.13 (SDA/D2), VFO1.3 (SDA)

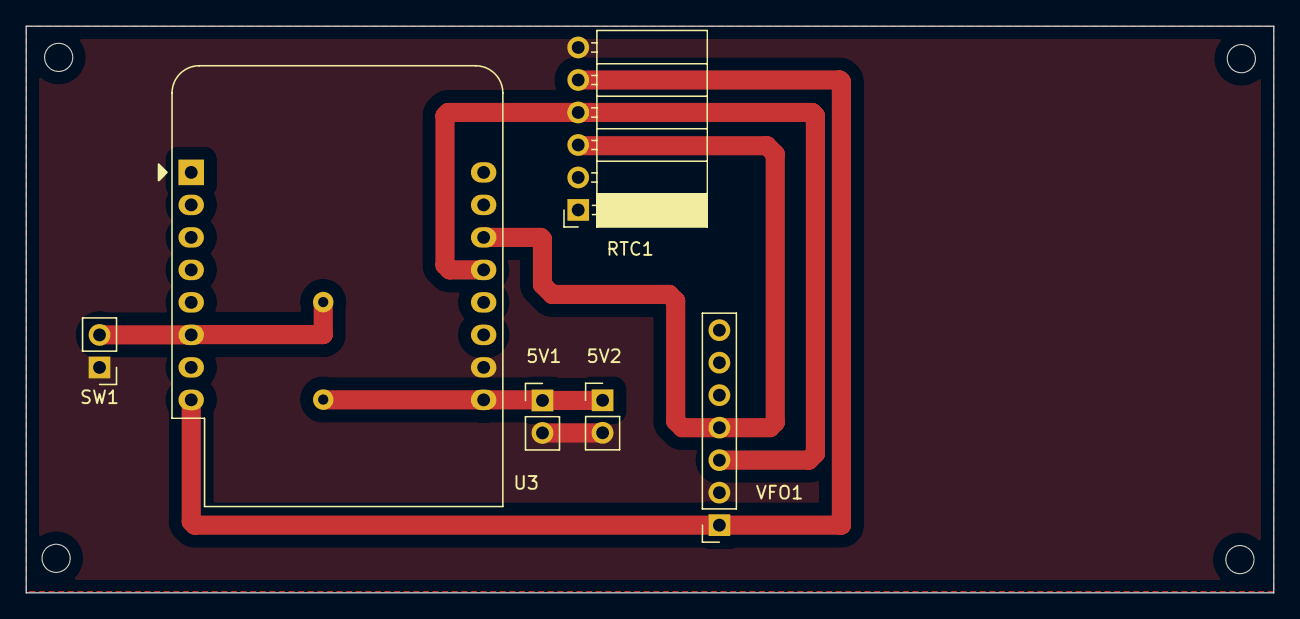
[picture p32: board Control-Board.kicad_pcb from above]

Board: 2 copper layers, 97.5 x 44.3 mm, 11 parts (1 on the bottom side), 6 nets.

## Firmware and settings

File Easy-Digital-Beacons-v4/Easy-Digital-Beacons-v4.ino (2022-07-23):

// Si5351 powered digital radio beacon. WeMos D1 Mini.
//
// Author: Dhiru Kholia (VU3CER), 21th-October-2021.
//
// Borrowed from:
// - https://github.com/iw5ejm/multibandWSPR_nodeMCU/blob/master/multibandWSPR_nodeMCU.ino
// - https://randomnerdtutorials.com/esp8266-web-server-spiffs-nodemcu/
// - https://randomnerdtutorials.com/esp8266-relay-module-ac-web-server/
// - https://randomnerdtutorials.com/esp8266-0-96-inch-oled-display-with-arduino-ide/
// - https://www.bakke.online/index.php/2017/06/02/self-updating-ota-firmware-for-esp8266/
// - https://github.com/anupamsaikia
//
// Required Libraries
// ------------------
// Etherkit Si5351 (Library Manager)
// Etherkit JTEncode (Library Manager)
// Time (Library Manager)
// Wire (Arduino Standard Library)
// RTClib
//
// https://www.arduinoslovakia.eu/application/timer-calculator

/*
  HTTP server stuff is borrowed from:

  Rui Santos
  Complete project details at https://RandomNerdTutorials.com

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
  The above copyright notice and this permission notice shall be included in all
  copies or substantial portions of the Software.
*/


#include <Arduino.h>

#include <JTEncode.h>
#include <FS.h>
#include <Wire.h>
#include <RTClib.h>
#include <si5351.h>
#include <TimeLib.h>
#include <WiFiUdp.h>
#include <NTPClient.h>
#include <uEEPROMLib.h>
#include <ESP8266mDNS.h>
#include <ESP8266WiFi.h>
#include <ESPAsyncTCP.h>
#include <ESPAsyncWebServer.h>
#include <rs_common.h>
#include <int.h>
#include <string.h>
#include "Wire.h"
#include <WiFiUdp.h>
#include <ESPAsyncWebServer.h>
#include "AsyncJson.h"
#include "ArduinoJson.h"
#include "SSD1306Wire.h"
#include "FT8.h"
#include "MyFont.h"

// WiFi credentials
#include "credentials.h"

// #define ENABLE_WSTJX_MODE 1  // FT8, FT4, and WSPR all work without any problems in WSJT-X mode!

// https://www.qsl.net/yo4hfu/SI5351.html says,
//
// If it is necessary, frequency correction must to be applied. My Si5351
// frequency was too high, correction used 1.787KHz at 10MHz. Open again
// Si5351Example sketch, set CLK_0 to 1000000000 (10MHz). Upload. Connect a
// accurate frequency counter to CLK_0 output pin 10. Correction factor:
// (Output frequency Hz - 10000000Hz) x 100. Example: (10001787Hz - 10000000Hz)
// x 100 = 178700 Note: If output frequency is less than 10MHz, use negative
// value of correction, example -178700.


// https://www.esp8266.com/wiki/doku.php?id=esp8266_gpio_pin_allocations
// The built-in led is on pin D4, and it is inverted.

// Global defines
#define PTT_PIN 14 // D5
// #define TX_LED_PIN 12 // D6
#define BUTTON_PIN D7
#define EEPROM_MODE_OFFSET 0
#define EEPROM_DELTA_OFFSET 4
#define EEPROM_TIME_DELTA_HACK_ENABLED_OFFSET 12
#define FREQUENCY_OFFSET 16
#define DELTA_DEFAULT 400


// Digital mode properties
#pragma region DigitalModeProperties
#define WSPR_TONE_SPACING 146 // ~1.46 Hz
#define FT8_TONE_SPACING 625  // ~6.25 Hz

#define WSPR_DELAY 683    // Delay value for WSPR
#define FT8_DELAY 159     // Delay value for FT8

#define WSPR_DEFAULT_FREQ 14097050UL
#define FT8_DEFAULT_FREQ 14075000UL
#define FT4_DEFAULT_FREQ 14081000UL
#pragma endregion DigitalModeProperties

// Enumerations
#pragma region Enums
enum DeviceModes
{
  STANDALONE,
  WEBSERVER,
  WSJTX
};

const String deviceModeTexts[] = {
  "Standalone",
  "Webserver",
  "WSJT-X",
};

enum OperatingModes
{
  MODE_WSPR,
  MODE_FT8,
  MODE_FT4,
};

const String operatingModeTexts[] = {
  "WSPR",
  "FT8",
  "FT4",
};
#pragma endregion Enums

// Class instantiations
int buttonState = 0;
RTC_DS3231 rtc;
Si5351 si5351;
DateTime dt;
JTEncode jtencode;
uEEPROMLib eeprom(0x57); // I2C EEPROM - incorporated on DS3231 RTC modules
unsigned long freq;
char message[] = "VU3CER VU3FOE MK68";
char call[] = "VU3FOE";
char loc[] = "MK68";
uint8_t dbm = 27;
uint8_t tx_buffer[255];  // NOTE
int rtc_lost_power = 0;
int vfo_ok = 1;
double delta = DELTA_DEFAULT;
uint32_t time_delta_hack_enabled = 0;
int beacon_enabled = 0;
const int ledPin = LED_BUILTIN;
enum codes
{
  NOP,
  LED_FLASH,
  NTP_SYNC,
  TUNE,
  TUNE_LONG,
  TUNE_POWER,
  MODE_SYNC,
  DELTA_SYNC,
  TIME_DELTA_HACK_SYNC,
  FREQUENCY_SYNC
};
enum modes
{
  FT8,
  FT4,
  WSPR,
};
enum modes mode = FT8; // Note
enum codes action = NOP;
#define str(x) #x
#define xstr(x) str(x)
const long utcOffsetInSeconds = (5.5 * 3600);
WiFiUDP ntpUDP;
NTPClient timeClient(ntpUDP, "pool.ntp.org", utcOffsetInSeconds);
AsyncWebServer server(80);
SSD1306Wire display(0x3c, SDA, SCL);
WiFiUDP Udp;

// common global states
#pragma region Common_Global_States
#ifdef ENABLE_WSTJX_MODE
DeviceModes deviceMode = WSJTX;      // default device mode is standalone
#else
DeviceModes deviceMode = STANDALONE;
#endif
OperatingModes operatingMode = MODE_FT8;   // default op mode is CW
uint64_t frequency = FT8_DEFAULT_FREQ * 100ULL;
int32_t si5351CalibrationFactor = 16999;  // si5351 calibration factor
boolean txEnabled = false;                // flag to denote if transmit is enabled or disabled
char txMessage[100] = "";                 // tx message
char myCallsign[10] = "VU3FOE";
char dxCallsign[10] = "VU3CER";
char myGridLocator[10] = "MK68";
uint8_t dBm = 30;
uint8_t txBuffer[255];
uint8_t symbolCount;
uint16_t toneDelay, toneSpacing;
char IP[16] = "0.0.0.0";
boolean refreshDisplay = false;

// Loop through the string, transmitting one character at a time.
void jtTransmitMessage()
{
  uint8_t i;

  Serial.println("TX!");
  txEnabled = true;
  updateDisplay();
  // Reset the tone to the base frequency and turn on the output
  si5351.set_clock_pwr(SI5351_CLK0, 1);
  si5351.output_enable(SI5351_CLK0, 1);
  digitalWrite(LED_BUILTIN, LOW);
  digitalWrite(PTT_PIN, HIGH); // Note

  for (i = 0; i < symbolCount; i++)
  {
    si5351.set_freq(frequency + (txBuffer[i] * toneSpacing), SI5351_CLK0);
    delay(toneDelay);
  }

  // Turn off the output
  si5351.set_clock_pwr(SI5351_CLK0, 0);
  si5351.output_enable(SI5351_CLK0, 0);
  digitalWrite(PTT_PIN, LOW);
  digitalWrite(LED_BUILTIN, HIGH);
  txEnabled = false;
  updateDisplay();
}

void setTxBuffer()
{
  // Clear out the transmit buffer
  memset(txBuffer, 0, sizeof(txBuffer));

  // Set the proper frequency and timer CTC depending on mode
  switch (operatingMode)
  {
    case MODE_WSPR:
      jtencode.wspr_encode(myCallsign, myGridLocator, dBm, txBuffer);
      break;
  }
}

String getTemperature()
{
  return String(rtc.getTemperature());
}

String getTime()
{
  char date[10] = "hh:mm:ss";
  rtc.now().toString(date);

  return date;
}

// Replaces placeholders in HTML code
String processor(const String &var)
{
  // Serial.println(var);
  if (var == "STATE")
  {
    if (digitalRead(ledPin))
    {
      return "OFF";
    }
    else
    {
      return "ON";
    }
  }
  else if (var == "RTC_LOST_POWER_STATE")
  {
    if (rtc_lost_power)
    {
      return "Yes";
    }
    else
    {
      return "No";
    }
  }
  else if (var == "VFO_OK")
  {
    if (vfo_ok)
    {
      return "Yes";
    }
    else
    {
      return "No";
    }
  }
  else if (var == "TIME_DELTA_HACK_ENABLED")
  {
    if (time_delta_hack_enabled)
    {
      return "Yes";
    }
    else
    {
      return "No";
    }
  }
  else if (var == "FT8_MESSAGE")
  {
    return String(message);
  }
  else if (var == "FREQUENCY")
  {
    return String(freq);
  }
  else if (var == "DELTA")
  {
    return String(delta);
  }
  else if (var == "TEMPERATURE")
  {
    return getTemperature();
  }
  else if (var == "TIME")
  {
    return getTime();
  }
  else if (var == "MODE")
  {
    if (mode == FT8)
      return String(xstr(FT8));
    else if (mode == FT4)
      return String(xstr(FT4));
    else if (mode == WSPR)
      return String(xstr(WSPR));
  }

  return "FAIL";
}

void AnnounceServices()
{
  MDNS.announce();
}

// debug helper
void led_flash()
{
  digitalWrite(LED_BUILTIN, HIGH);
  delay(250);
  digitalWrite(LED_BUILTIN, LOW);
  delay(250);
  digitalWrite(LED_BUILTIN, HIGH);
  delay(250);
  digitalWrite(LED_BUILTIN, LOW);
  delay(250);
  digitalWrite(LED_BUILTIN, HIGH);
  delay(250);
  digitalWrite(LED_BUILTIN, LOW);
  delay(250);
  digitalWrite(LED_BUILTIN, HIGH);
}


// WSJTX UDP
#pragma region WSJTX
const unsigned int localUdpPort = 2237; // local port to listen on
uint8_t WSJTX_incomingByteArray[255];   // buffer for incoming packets
size_t WSJTX_currentIndex = 0;

// WSJTX helper functions
uint8 readuInt8()
{
  uint8 val;
  memcpy(&val, &WSJTX_incomingByteArray[WSJTX_currentIndex], sizeof(val));
  WSJTX_currentIndex += 1;
  return val;
}

uint32 readuInt32()
{
  uint32 bigEndianValue;
  memcpy(&bigEndianValue, &WSJTX_incomingByteArray[WSJTX_currentIndex], sizeof(bigEndianValue));
  WSJTX_currentIndex += 4;
  uint32 theUnpackedValue = ntohl(bigEndianValue);
  return theUnpackedValue;
}

int32 readInt32()
{
  int32 bigEndianValue;
  memcpy(&bigEndianValue, &WSJTX_incomingByteArray[WSJTX_currentIndex], sizeof(bigEndianValue));
  WSJTX_currentIndex += 4;
  int32 theUnpackedValue = ntohl(bigEndianValue);
  return theUnpackedValue;
}

uint64 readuInt64()
{
  uint64 bigEndianValue;
  memcpy(&bigEndianValue, &WSJTX_incomingByteArray[WSJTX_currentIndex], sizeof(bigEndianValue));
  WSJTX_currentIndex += 8;
  uint64 theUnpackedValue = __builtin_bswap64(bigEndianValue);
  return theUnpackedValue;
}

bool readBool()
{
  bool val;
  memcpy(&val, &WSJTX_incomingByteArray[WSJTX_currentIndex], sizeof(val));
  WSJTX_currentIndex += 1;
  return val;
}

#pragma endregion WSJTX

// Display functionality
#pragma region Display

// Primary frame. Shows the most important device states
void showScreen1()
{
  display.clear();

  display.setFont(Roboto_Mono_Thin_16);
  display.drawString(0, 0, String((double)frequency / 100000000, 6U) + "MHz");

  display.setFont(ArialMT_Plain_10);
  display.drawString(0, 20, "Mode: " + deviceModeTexts[deviceMode]);
  display.drawString(0, 30, "OpMode: " + operatingModeTexts[operatingMode]);
  display.drawString(0, 40, "IP: " + String(IP));
  display.drawString(0, 50, "TxEnabled: " + String(txEnabled ? "true" : "false"));
  display.display();
}

void showScreenWSJTX()
{
  display.clear();

  display.setFont(Roboto_Mono_Thin_16);
  display.drawString(0, 0, String((double)frequency / 100000000, 6U) + "MHz");

  display.setFont(ArialMT_Plain_10);
  display.drawString(0, 20, "DeviceMode: " + deviceModeTexts[deviceMode]);
  display.drawString(0, 30, "OpMode: " + operatingModeTexts[operatingMode]);
  if (operatingMode == MODE_WSPR)
  {
    display.drawString(0, 40, myCallsign + String(" ") + myGridLocator + String(" ") + String(dBm));
  }
  else
  {
    display.drawString(0, 40, String(txMessage));
  }
  display.drawString(0, 50, "TxEnabled: " + String(txEnabled ? "true" : "false"));

  display.display();
}

void updateDisplay()
{
  if (deviceMode == WSJTX)
  {
    showScreenWSJTX();
  }
  else
  {
    showScreen1();
  }
}

#pragma endregion Display

void set_mode()
{
  eeprom.eeprom_read(EEPROM_MODE_OFFSET, &mode);
  if (mode != FT8 && mode != FT4 && mode != WSPR) {
    Serial.println("EEPROM has corrupt mode setting, do a save ;)");
    mode = FT8;
  }
  eeprom.eeprom_read(EEPROM_DELTA_OFFSET, &delta);
  if (delta != delta) { // NaN
    delta = DELTA_DEFAULT;
  }
  eeprom.eeprom_read(EEPROM_TIME_DELTA_HACK_ENABLED_OFFSET, &time_delta_hack_enabled);
  if (time_delta_hack_enabled != 0 && time_delta_hack_enabled != 1) {
    time_delta_hack_enabled = 0;
  }

  if (mode == WSPR) {
    frequency = WSPR_DEFAULT_FREQ * 100ULL;;
    symbolCount = WSPR_SYMBOL_COUNT;
    toneSpacing = WSPR_TONE_SPACING;
    toneDelay = WSPR_DELAY;
    operatingMode = MODE_WSPR;
    setTxBuffer();
    Serial.println("Getting ready for WSPR...");
  } else if (mode == FT8) {
    frequency = FT8_DEFAULT_FREQ * 100ULL;
    symbolCount = FT8_SYMBOL_COUNT;
    toneSpacing = FT8_TONE_SPACING;
    toneDelay = FT8_DELAY;
    operatingMode = MODE_FT8;
    ftx_encode(message, txBuffer, false);
  } else if (mode == FT4) {
    frequency = FT4_DEFAULT_FREQ * 100ULL;
    symbolCount = 105;
    toneSpacing = 2083.3333; // ~20.83 Hz
    toneDelay = 47;
    operatingMode = MODE_FT4;
    ftx_encode(message, txBuffer, true);
    Serial.print("FSK tones: ");
    for (int j = 0; j < symbolCount; ++j) {
      Serial.print(tx_buffer[j]);
    }
    Serial.println("\n");
  }
}
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
void loop()
{
  updateDisplay();
  delay(100);

#ifdef ENABLE_WSTJX_MODE
  // logic for device mode WSJTX
  // WSJTX message type: https://sourceforge.net/p/wsjt/wsjtx/ci/master/tree/Network/NetworkMessage.hpp#l141

  int packetSize = Udp.parsePacket();
  if (packetSize)
  {
    unsigned long now = millis();

    // receive incoming UDP packets
    int len = Udp.read(WSJTX_incomingByteArray, 255);
    if (len > 0)
    {
      WSJTX_currentIndex = 8; // skip packet header

      // Packet Type
      uint32 WSJTX_packetType = readuInt32();
      if (WSJTX_packetType == 1)
      {
        //--------------------------------------------------------------------//
        // Client id
        int32 WSJTX_clientIdLength = readInt32();
        char WSJTX_clientId[WSJTX_clientIdLength + 1];
        for (int32 i = 0; i < WSJTX_clientIdLength; i++)
        {
          WSJTX_clientId[i] = WSJTX_incomingByteArray[WSJTX_currentIndex];
          WSJTX_currentIndex += 1;
        }
        WSJTX_clientId[WSJTX_clientIdLength] = 0;

        //--------------------------------------------------------------------//
        // Dial Frequency
        uint64 WSJTX_dialFrequency = readuInt64();

        //--------------------------------------------------------------------//
        // Mode
        int32 WSJTX_modeLength = readInt32();
        char WSJTX_mode[WSJTX_modeLength + 1];
        for (int32 i = 0; i < WSJTX_modeLength; i++)
        {
          WSJTX_mode[i] = WSJTX_incomingByteArray[WSJTX_currentIndex];
          WSJTX_currentIndex += 1;
        }
        WSJTX_mode[WSJTX_modeLength] = 0;

        //--------------------------------------------------------------------//
        // DX Call
        int32 WSJTX_dxCallLength = readInt32();
        char WSJTX_dxCall[WSJTX_dxCallLength + 1];
        for (int32 i = 0; i < WSJTX_dxCallLength; i++)
        {
          WSJTX_dxCall[i] = WSJTX_incomingByteArray[WSJTX_currentIndex];
          WSJTX_currentIndex += 1;
        }
        WSJTX_dxCall[WSJTX_dxCallLength] = 0;

        //--------------------------------------------------------------------//
        // Report
        int32 WSJTX_reportLength = readInt32();
        char WSJTX_report[WSJTX_reportLength + 1];
        for (int32 i = 0; i < WSJTX_reportLength; i++)
        {
          WSJTX_report[i] = WSJTX_incomingByteArray[WSJTX_currentIndex];
          WSJTX_currentIndex += 1;
        }
        WSJTX_report[WSJTX_reportLength] = 0;

        //--------------------------------------------------------------------//
        // Tx mode
        int32 WSJTX_txModeLength = readInt32();
        char WSJTX_txMode[WSJTX_txModeLength + 1];
        for (int32 i = 0; i < WSJTX_txModeLength; i++)
        {
          WSJTX_txMode[i] = WSJTX_incomingByteArray[WSJTX_currentIndex];
          WSJTX_currentIndex += 1;
        }
        WSJTX_txMode[WSJTX_txModeLength] = 0;

        //--------------------------------------------------------------------//
        // Tx Enabled
        bool WSJTX_txEnabled = readBool();

        //--------------------------------------------------------------------//
        // Transmitting
        bool WSJTX_transmitting = readBool();

        //--------------------------------------------------------------------//
        // Decoding
        bool WSJTX_decoding = readBool();

        //--------------------------------------------------------------------//
        // Rx DF
        uint32 WSJTX_rxDF = readuInt32();

        //--------------------------------------------------------------------//
        // Tx DF
        uint32 WSJTX_txDF = readuInt32();

        //--------------------------------------------------------------------//
        // DE call
        int32 WSJTX_deCallLength = readInt32();
        char WSJTX_deCall[WSJTX_deCallLength + 1];
        for (int32 i = 0; i < WSJTX_deCallLength; i++)
        {
          WSJTX_deCall[i] = WSJTX_incomingByteArray[WSJTX_currentIndex];
          WSJTX_currentIndex += 1;
        }
        WSJTX_deCall[WSJTX_deCallLength] = 0;

        //--------------------------------------------------------------------//
        // DE grid
        int32 WSJTX_deGridLength = readInt32();
        char WSJTX_deGrid[WSJTX_deGridLength + 1];
        for (int32 i = 0; i < WSJTX_deGridLength; i++)
        {
          WSJTX_deGrid[i] = WSJTX_incomingByteArray[WSJTX_currentIndex];
          WSJTX_currentIndex += 1;
        }
        WSJTX_deGrid[WSJTX_deGridLength] = 0;

        //--------------------------------------------------------------------//
        // DX grid
        int32 WSJTX_dxGridLength = readInt32();
        char WSJTX_dxGrid[WSJTX_dxGridLength + 1];
        for (int32 i = 0; i < WSJTX_dxGridLength; i++)
        {
          WSJTX_dxGrid[i] = WSJTX_incomingByteArray[WSJTX_currentIndex];
          WSJTX_currentIndex += 1;
        }
        WSJTX_dxGrid[WSJTX_dxGridLength] = 0;

        //--------------------------------------------------------------------//
        // Tx Watchdog
        bool WSJTX_txWatchdog = readBool();

        //--------------------------------------------------------------------//
        // Sub-mode
        int32 WSJTX_subModeLength = readInt32();
        char WSJTX_subMode[WSJTX_subModeLength + 1];
        for (int32 i = 0; i < WSJTX_subModeLength; i++)
        {
          WSJTX_subMode[i] = WSJTX_incomingByteArray[WSJTX_currentIndex];
          WSJTX_currentIndex += 1;
        }
        WSJTX_subMode[WSJTX_subModeLength] = 0;

        //--------------------------------------------------------------------//
        // Fast mode
        bool WSJTX_fastMode = readBool();

        //--------------------------------------------------------------------//
        // Special Operation Mode
        uint8 WSJTX_specialOpMode = readuInt8();

        // Frequency Tolerance
        uint32 WSJTX_frequencyTolerance = readuInt32();

        //--------------------------------------------------------------------//
        // T/R Period
        uint32 WSJTX_txrxPeriod = readuInt32();

        //--------------------------------------------------------------------//
        // Configuration Name
        int32 WSJTX_configNameLength = readInt32();
        char WSJTX_configName[WSJTX_configNameLength + 1];
        for (int32 i = 0; i < WSJTX_configNameLength; i++)
        {
          WSJTX_configName[i] = WSJTX_incomingByteArray[WSJTX_currentIndex];
          WSJTX_currentIndex += 1;
        }
        WSJTX_configName[WSJTX_configNameLength] = 0;

        //--------------------------------------------------------------------//
        // Tx Message
        int32 WSJTX_txMessageLength = readInt32();
        // Funfact: While testing, I got WSJTX_txMessageLength=37 regardless of the actual message length.
        // Therefore, WSJTX_txMessage needs to be trimmed.
        char WSJTX_txMessage[WSJTX_txMessageLength + 1];
        for (int32 i = 0; i < WSJTX_txMessageLength; i++)
        {
          WSJTX_txMessage[i] = WSJTX_incomingByteArray[WSJTX_currentIndex];
          WSJTX_currentIndex += 1;
        }
        WSJTX_txMessage[WSJTX_txMessageLength] = 0;

        // set frequency
        frequency = (WSJTX_dialFrequency + WSJTX_txDF) * 100ULL;

        // trim tx message
        String newTxMessage = String(WSJTX_txMessage);
        newTxMessage.trim();

        if (strcmp(WSJTX_mode, "FT8") == 0)
        {
          symbolCount = FT8_SYMBOL_COUNT;
          toneSpacing = FT8_TONE_SPACING;
          toneDelay = FT8_DELAY;
          operatingMode = MODE_FT8;
          txEnabled = WSJTX_txEnabled;
          strcpy(txMessage, newTxMessage.c_str());
        }
        else if (strcmp(WSJTX_mode, "FT4") == 0)
        {
          symbolCount = 105;
          toneSpacing = 2083.3333; // ~20.83 Hz
          toneDelay = 47;
          operatingMode = MODE_FT4;
          txEnabled = WSJTX_txEnabled;
          strcpy(txMessage, newTxMessage.c_str());
        }
        else if (strcmp(WSJTX_mode, "WSPR") == 0)
        {
          symbolCount = 160;
          toneSpacing = WSPR_TONE_SPACING;
          toneDelay = WSPR_DELAY;
          operatingMode = MODE_WSPR;
          txEnabled = WSJTX_txEnabled;
          strcpy(myCallsign, WSJTX_deCall);
          strcpy(myGridLocator, WSJTX_deGrid);
          // dbm value is not taken from WSJTX.
          // Enter correct dbm value from the web interface
        }
        else
        {
          txEnabled = false;
        }

        // update display
        updateDisplay();
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

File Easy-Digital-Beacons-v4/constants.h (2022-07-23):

#ifndef _INCLUDE_CONSTANTS_H_
#define _INCLUDE_CONSTANTS_H_

#include <stdint.h>

typedef enum
{
    PROTO_FT4,
    PROTO_FT8
} ftx_protocol_t;

#define FT8_SYMBOL_PERIOD (0.160f) ///< FT8 symbol duration, defines tone deviation in Hz and symbol rate
#define FT8_SLOT_TIME (15.0f)      ///< FT8 slot period

#define FT4_SYMBOL_PERIOD (0.048f) ///< FT4 symbol duration, defines tone deviation in Hz and symbol rate
#define FT4_SLOT_TIME (7.5f)       ///< FT4 slot period

// Define FT8 symbol counts
// FT8 message structure:
//     S D1 S D2 S
// S  - sync block (7 symbols of Costas pattern)
// D1 - first data block (29 symbols each encoding 3 bits)
#define FT8_ND (58)          ///< Data symbols
#define FT8_NN (79)          ///< Total channel symbols (FT8_NS + FT8_ND)
#define FT8_LENGTH_SYNC (7)  ///< Length of each sync group
#define FT8_NUM_SYNC (3)     ///< Number of sync groups
#define FT8_SYNC_OFFSET (36) ///< Offset between sync groups

// Define FT4 symbol counts
// FT4 message structure:
//     R Sa D1 Sb D2 Sc D3 Sd R
// R  - ramping symbol (no payload information conveyed)
// Sx - one of four _different_ sync blocks (4 symbols of Costas pattern)
// Dy - data block (29 symbols each encoding 2 bits)
#define FT4_ND (87)          ///< Data symbols
#define FT4_NR (2)           ///< Ramp symbols (beginning + end)
#define FT4_NN (105)         ///< Total channel symbols (FT4_NS + FT4_ND + FT4_NR)
#define FT4_LENGTH_SYNC (4)  ///< Length of each sync group
#define FT4_NUM_SYNC (4)     ///< Number of sync groups
#define FT4_SYNC_OFFSET (33) ///< Offset between sync groups

// Define LDPC parameters
#define FTX_LDPC_N (174)                        ///< Number of bits in the encoded message (payload with LDPC checksum bits)
#define FTX_LDPC_K (91)                         ///< Number of payload bits (including CRC)
#define FTX_LDPC_M (83)                         ///< Number of LDPC checksum bits (FTX_LDPC_N - FTX_LDPC_K)
#define FTX_LDPC_N_BYTES ((FTX_LDPC_N + 7) / 8) ///< Number of whole bytes needed to store 174 bits (full message)
#define FTX_LDPC_K_BYTES ((FTX_LDPC_K + 7) / 8) ///< Number of whole bytes needed to store 91 bits (payload + CRC only)

// Define CRC parameters
#define FT8_CRC_POLYNOMIAL ((uint16_t)0x2757u) ///< CRC-14 polynomial without the leading (MSB) 1
#define FT8_CRC_WIDTH (14)

/// Costas 7x7 tone pattern for synchronization
extern const uint8_t kFT8_Costas_pattern[7];
extern const uint8_t kFT4_Costas_pattern[4][4];

/// Gray code map to encode 8 symbols (tones)
extern const uint8_t kFT8_Gray_map[8];
extern const uint8_t kFT4_Gray_map[4];

extern const uint8_t kFT4_XOR_sequence[10];

/// Parity generator matrix for (174,91) LDPC code, stored in bitpacked format (MSB first)
extern const uint8_t kFTX_LDPC_generator[FTX_LDPC_M][FTX_LDPC_K_BYTES];

/// LDPC(174,91) parity check matrix, containing 83 rows,
/// each row describes one parity check,
/// each number is an index into the codeword (1-origin).
/// The codeword bits mentioned in each row must xor to zero.
/// From WSJT-X's ldpc_174_91_c_reordered_parity.f90.
extern const uint8_t kFTX_LDPC_Nm[FTX_LDPC_M][7];

/// Mn from WSJT-X's bpdecode174.f90. Each row corresponds to a codeword bit.
/// The numbers indicate which three parity checks (rows in Nm) refer to the codeword bit.
/// The numbers use 1 as the origin (first entry).
extern const uint8_t kFTX_LDPC_Mn[FTX_LDPC_N][3];

/// Number of rows (columns in C/C++) in the array Nm.
extern const uint8_t kFTX_LDPC_Num_rows[FTX_LDPC_M];

#endif // _INCLUDE_CONSTANTS_H_

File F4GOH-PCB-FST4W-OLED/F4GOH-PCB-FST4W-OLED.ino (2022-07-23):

// Huge thanks to https://github.com/f4goh/ for the original FST4W work!
//
// Huge thanks to IK1HGI (Antonio) for introducing me to FST4W and the top band!
//
// Reference: https://physics.princeton.edu/pulsar/k1jt/FST4_Quick_Start.pdf

// GPS stuff
#include <TinyGPS++.h>
TinyGPSPlus gps;
// #include <AltSoftSerial.h>
// AltSoftSerial altSerial;  // Uses pin 8 (D8) for RX on Arduino Nano -> a LED is on pin 8, so we can't use AltSoftSerial
#include <SoftwareSerial.h>
SoftwareSerial altSerial(4, 5); // RX, TX (GPS) -> D4, D5
// RTC stuff
#include <RTClib.h>
#include <si5351.h>
#include <TimeLib.h>
RTC_DS3231 rtc;
DateTime dt;

#define FST4W_SYMBOL_COUNT  160

// Select frequency below
#define FST4W_DEFAULT_FREQ  475700UL // 475700 - 1500 (factor) = 474200 KHz band (630m band)! Tune receiver to 474.200 KHz USB!
// #define FST4W_DEFAULT_FREQ  137450UL // Antonio's frequency (2200m band)
// #define FST4W_DEFAULT_FREQ  14097050UL  // 20 meter band for testing
long factor = -1500; // adjust frequency to wspr band

// fst4sim "IK1HGI JN45 20" 120 1500 0.0 0.1 1.0 10 -15 F
const uint8_t FST4Wsymbols[FST4W_SYMBOL_COUNT] = { 0, 1, 3, 2, 1, 0, 2, 3, 3, 0, 3, 3, 0, 3, 1, 0, 0, 2, 2, 1, 3, 1, 3, 0, 3, 1, 0, 1, 0, 3, 1, 3, 0, 0, 3, 0, 1, 1, 2, 3, 1, 0, 3, 2, 0, 1, 0, 3, 1, 2, 1, 2, 3, 2, 1, 1, 0, 0, 1, 3, 3, 1, 3, 0, 0, 2, 3, 1, 2, 0, 3, 0, 2, 2, 1, 2, 0, 1, 3, 2, 1, 0, 2, 3, 0, 3, 0, 3, 2, 2, 0, 1, 0, 2, 0, 1, 0, 0, 2, 2, 3, 1, 3, 0, 2, 1, 1, 3, 0, 1, 0, 3, 2, 2, 2, 3, 1, 0, 3, 2, 0, 1, 0, 0, 3, 2, 1, 2, 0, 2, 2, 0, 3, 0, 0, 1, 3, 3, 3, 0, 0, 0, 1, 3, 2, 1, 1, 0, 0, 2, 0, 2, 0, 1, 3, 2, 1, 0, 2, 3 };

// Note - Change me for using a different FST4W mode!
uint8_t FST4W_MODE = 0; // Use 'Serial Port Commands' to change mode
// 0 = FST4W 120
// 1 = FST4W 300
// 2 = FST4W 900
// 3 = FST4W 1800

float toneSpacing[4] = {
  1.464,   // 120
  0.558,   // 300
  0.1803,  // 900
  0.08929  // 1800
};

// Load WSPR/FST4W symbol length
unsigned int symbolLength[4] = {
  683,    // 120
  1792,   // 300
  5547,   // 900
  11200   // 1800
};

enum OperatingModes
{
  MODE_FST4W,
};

enum modes
{
  FST4W,
};
enum modes mode = FST4W; // Note

#define IS_GPS_SYNCED_PIN 3 // D3

#include <EEPROM.h>
#include <Wire.h>
#include <SPI.h>

#include "SSD1306Ascii.h"
#include "SSD1306AsciiWire.h"
// 0X3C+SA0 - 0x3C or 0x3D
#define I2C_ADDRESS 0x3C
#define RST_PIN -1
SSD1306AsciiWire oled;  //afficheur oled;

#define LED 8
#define W_CLK 13
#define FQ_UD 10
#define RESET 9
#define GAIN 6  // pwm output pinout to adjust gain (mos polarization)
uint64_t FREQUENCY = FST4W_DEFAULT_FREQ;


#define PWM_GAIN 170      // continous voltage ctrl for mosfet R3=1K and R4=4.7K

int secPrec = 0;
int rtc_lost_power = 0;

int gain = PWM_GAIN;
tmElements_t tm;

void updateDisplay()
{
  oled.clear();
  oled.setCursor(0, 0);
  oled.print(FST4W_MODE);
  delay(1000);
}

void sync_time_with_gps_with_timeout()
{
  digitalWrite(IS_GPS_SYNCED_PIN, LOW);
  bool newData = false;

  oled.clear();
  oled.setCursor(0, 0);
  oled.print(F("GPS Sync Wait..."));
  delay(500);

  altSerial.begin(9600);

  for (unsigned long start = millis(); millis() - start < 32000;)
  {
    while (altSerial.available())
    {
      char c = altSerial.read();
#ifdef debugGPS
      Serial.write(c);
#endif
      if (gps.encode(c)) // Did a new valid sentence come in?
        newData = true;
    }
    if (newData && gps.time.isUpdated() && gps.date.isUpdated() && (gps.location.isValid() && gps.location.age() < 2000)) {
      byte Year = gps.date.year();
      byte Month = gps.date.month();
      byte Day = gps.date.day();
      byte Hour = gps.time.hour();
      byte Minute = gps.time.minute();
      byte Second = gps.time.second();
      rtc.adjust(DateTime(Year, Month, Day, Hour, Minute, Second));
      digitalWrite(IS_GPS_SYNCED_PIN, HIGH);
      oled.clear();
      oled.setCursor(0, 0);
      Serial.println(F("GPS Sync Done!"));
      delay(2000);
      return;
    }
  }
  Serial.println(F("GPS Sync Failed!"));
  oled.clear();
}

void setup()
{
  // Safety first!
  pinMode(IS_GPS_SYNCED_PIN, OUTPUT);
  digitalWrite(IS_GPS_SYNCED_PIN, LOW);

  Wire.begin();
  Wire.setClock(400000L);
  Serial.begin(9600);
  Serial.print("Hello! :-)");
  pinMode(LED, OUTPUT);
  pinMode(GAIN, OUTPUT);
  analogWrite(GAIN, 0);
#if RST_PIN >= 0
  oled.begin(&Adafruit128x64, I2C_ADDRESS, RST_PIN);
#else // RST_PIN >= 0
  oled.begin(&Adafruit128x64, I2C_ADDRESS);
#endif // RST_PIN >= 0
  oled.setFont(TimesNewRoman16_bold);
  oled.clear();
  oled.setCursor(5, 0);
  oled.println(F("WSPR"));
  oled.setCursor(5, 5); // x, y
  oled.print(F("IK1HGI 2022"));
  oled.setFont(fixednums15x31); // Change this to change the clock font size
  delay(2000);
  oled.clear();

  // DDS
  initDds();
  setfreq(0, 0);
  setfreq(0, 0);

  // RTC
  // Initialize the rtc
  if (!rtc.begin()) {
    Serial.println(F("Couldn't find RTC!"));
    Serial.flush();
    abort();
  }
  if (rtc.lostPower()) {
    Serial.println(F("RTC lost power, continue!?"));
    Serial.flush();
    rtc_lost_power = 1;
    // rtc.adjust(DateTime(F(__DATE__), F(__TIME__))); // hack!
    // abort();  // NOTE
  }


  int n, lf;
  lf = 0;
  for (n = 0; n < FST4W_SYMBOL_COUNT; n++) {   // print symbols on serial monitor
    if (lf % 16 == 0) {
      Serial.println();
      Serial.print(n);
      Serial.print(": ");
    }
    lf++;
    Serial.print(FST4Wsymbols[n]);
    Serial.print(',');
  }
  Serial.println();
  sync_time_with_gps_with_timeout();
  Serial.println("Ready to roll...");
}
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
